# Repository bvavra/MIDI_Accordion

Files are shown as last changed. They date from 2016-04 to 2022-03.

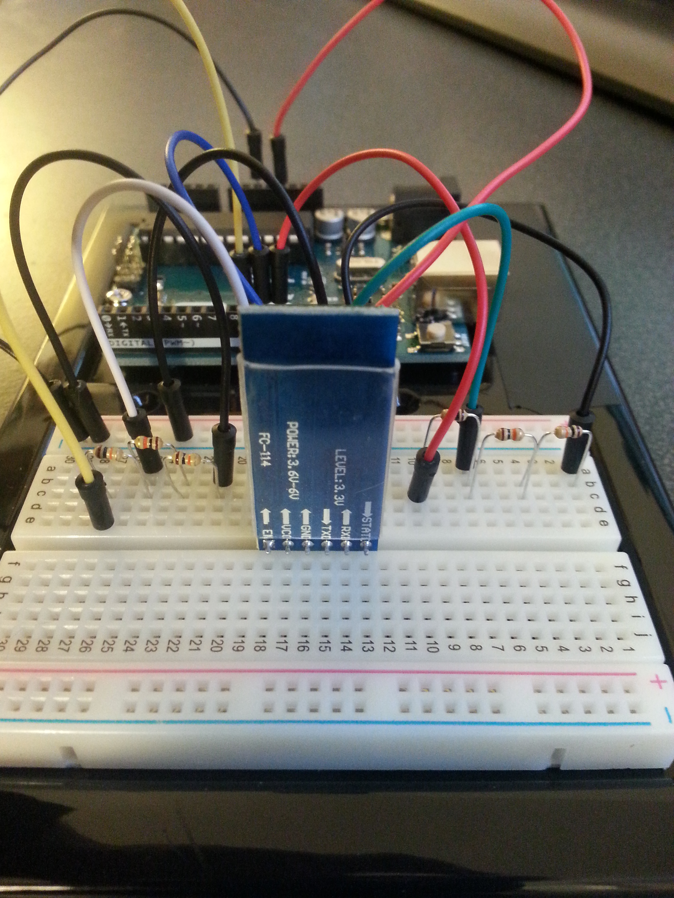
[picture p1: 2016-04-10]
Prototypes/Bluetooth/Bluetooth_Tutorial_2/bluetooth_fig2b_arduino.jpg

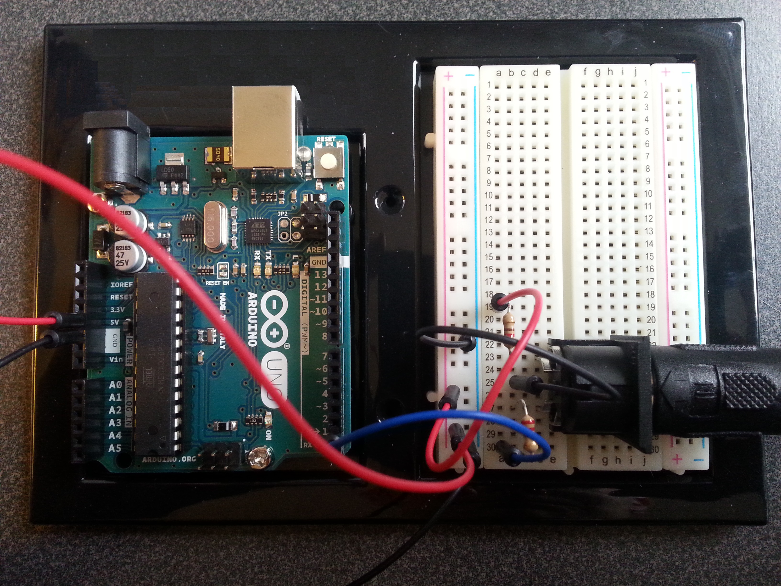
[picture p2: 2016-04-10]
Prototypes/MIDI_Tutorial/midi_fig1_arduino.jpg

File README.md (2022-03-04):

# DIY MIDI Accordion
Schematics, code, and guide for building your own Arduino-powered MIDI accordion _(based off Dmitry Yegorenkov's [AccordionMega project](https://github.com/accordion-mega/AccordionMega))_

### [Full Project Page](http://bvavra.github.io/MIDI_Accordion/)

### [Donate](https://www.paypal.com/donate/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)

### Photos

[MIDI Accordion Project Photo Gallery](http://imgur.com/a/U7L83)

### Videos

[Demo Video #1 - Professor Layton Main Theme (Intro)](https://www.youtube.com/watch?v=s197ojk8npI)

[Demo Video #2 - Stolen Moments (by Oliver Nelson)](https://www.youtube.com/watch?v=Z_4_YdG65XQ)

[Demo Video #3 - Everfrost Peak (from Diddy Kong Racing)](https://www.youtube.com/watch?v=8d2E2YQPqnI)

[Demo Video #4 - Stickerbrush Symphony (from Donkey Kong Country 2)](https://youtu.be/sQWZQSPkWCQ)

| Table of Contents      |
| ---------------------- |
| [Overview](#overview)  |
| [Changelog](#changelog)|
| [Materials](#materials)|
| [Software](#software)  |
| [Quick Guide](#guide)  |
| [Links](#links)        |

## Overview

The goal of this project is to take a traditional piano accordion and turn it into a MIDI controller capable of playing music through your computer.  To do this requires solving a few different problems; the finished MIDI Accordion needs to be able to:

1. Send a digital signal from the accordion keys and buttons to the computer
2. Convert that signal to MIDI
3. Play that signal back with music software
4. Communicate that signal for each button on the accordion

The above goals are enough to have a functional MIDI instrument, but there are a few additional "nice to have" requirements that can also be implemented, such as the ability to:

5. Communicate MIDI signals wirelessly (via Bluetooth)
6. Decouple the accordion's power supply from the computer/wall
7. Add dynamic expression using the accordion bellows (via barometric pressure sensor)
8. Add other expressions such as pitch bend, panning, and other sound control effects with potentiometers (sliders, knobs, joysticks, etc.)

_Note: In the project, the computer is **required** for playback; this project does **not** involve installing speakers to play back MIDI-realized sound directly from the accordion.  I may delve into such a feat someday, but today is not that day._

## Changelog

### v1.3.00 (10/2/2017)

- Added joystick to control pitch bend
    - Can be configured (at compile time) to bend pitch up or down
	- Can be configured (at compile time) to bend pitch for melody, bass, and/or chords
- **Breaking Change!** - Opto-interruptor pin connections have been moved in order to free up analog and PWM pins for future components.  If you are upgrading to v1.3 from an earlier version you will need to adjust your Arduino pin connections and/or code.  [Schematics and Breadboard docs](https://github.com/bvavra/MIDI_Accordion/tree/master/MIDI_Accordion/schematics) have been updated accordingly.

### v1.2.00 (1/2/2017)

- Added BMP180 support, allowing changes in pressure from moving bellows to change MIDI expression (i.e. volume)
   - Made the following changes from the original [AccordionMega](https://github.com/accordion-mega/AccordionMega) BMP085 code:
       - Updated the temperature and pressure reading code to use SparkFun's BMP180 library.
	   - Updated pressure<->velocity mapping algorithm according to various play tests.
       - Pressure is now read asynchronously from the Arduino - adds approximately 2ms delay when enabled (original added delay was about 3-5ms).

### v1.1.00 (12/28/2016)

- Added Bluetooth support (e.g. HC-05), allowing MIDI data to communicate wirelessly instead of over USB
    - Uses #DEFINE variable to toggle between using USB and additional serial port at compile time to reduce bandwidth usage

### v1.0.00 (12/09/2016)

- First working version of final project with all accordion keys mapped according to bvavra's PCB design.
- Made the following changes from the original [AccordionMega](https://github.com/accordion-mega/AccordionMega) code:
    - Updated files (and syntax) from .pde to .ino (new Arduino IDE)
    - Removed register shift code 
	    - Although it's a cool idea that could be realized on the accordion by adding some digital register buttons, I've decided to keep things simple and only transmit one register per button and control which registers sound via MIDI playback software (e.g. Logic, Reason, etc.)
    - Shaved off 2-3 ms of latency by reorganizing how the opto-interruptors are read.
    - Updated MIDI code to use Arduino MIDI Library
    - Added some extra comments to explain what some of the more obtuse lines are doing (port manipulation, bit operations, etc.)

## Materials

The final project requires the following materials and components:

**Item Name (Part Number)**|**Quantity**
:-----:|:-----:
Accordion|1
Arduino Mega 2560 R3|1
Barometric Pressure Sensor (BMP 180)|1
Bluetooth Transceiver Module (HC-05 RS232)|1
USB Bluetooth Dongle|1
Photo/Opto Interruptor (ITR-9608)|65
270 Ohm Resistor 1/4W 5%|65
1k Ohm Resistor 1/4W 5%|9
2k Ohm Resistor 1/4W 5%|1
BJT NPN Transistor (2N 2222A)|8
Black 8" Zip Ties|65
USB 2.0 Type A Type B M/M Cable|1
USB 2.0 Type A to Type B F/F Adapter Header|1
SB404 PCB (BB400)|2
BR1 PCB (830)|5
.5"x.5" 90 Degree Angle Corner Plate (H# 884487)|10
2.54mm Breakaway PCB Board 40 Pin Header Kit|1
2.54mm Dupont M/F 40 Pin Connector Kit|1
Multicolored Jumper Wire Ribbon Cable Kit|1
M3 M/F Brass Spacer Standoff Assortment Kit|1
Threaded Insert M3 9.52mm|8
White 4" Zip Ties (100pc)|1

The total cost of these materials can vary. [The original accordion project](https://github.com/accordion-mega/AccordionMega/wiki/Accordion-Mega-story) cost under $100.  If you exclude the accordion, I spent about $220 on the above materials.  If you don't have an accordion you can get a decent enough one on eBay for as low as $100 (normally I'd advise against buying an accordion off eBay, but it doesn't have to sound good; it just needs to function mechanically).  I bought mine for $150 (plus $30 shipping), bringing my project's grand total cost to about $400.

You will also need the following tools:

**Item**|**Usage**
:-----:|:-----:
Multimeter|Used to debug circuit connectivity.
Soldering Iron|Used to join components to the circuit boards.
60-40 Rosin Core Solder|Used to create circuit joints.
Brass Wire and Holder|Used to clean the soldering iron tip.
Desoldering Wick/Pump/Bulb|Used to fix soldering mistakes.
Adjustable Circuit Board Holder|Used to hold the circuit board in place while soldering.
Wire Strippers|Used to cut and strip wires to size.
Wire Cutters|Used to trim wires and components after they've been soldered.
Utility Knife|Used to cut the circuit boards and sever bad solder connections.
Sandpaper|Used to smooth cuts made to circuit boards.
Power Drill|Used to drill holes in the circuit boards and the accordion.
Small Flathead Screwdriver (c.1/8")|Used to open up and take apart the accordion.
Crimping pliers|(Optional) Used to make jumper wire ends.

I had to buy most of these tools for this project, which rang up to about $100 total.

## Software

### Project Source Code

The only files required for the final project are the Arduino files located in the root level [MIDI_Accordion directory](https://github.com/bvavra/MIDI_Accordion/tree/master/MIDI_Accordion).  Everything else in this repo is supplemental information to help research and build the project (e.g. Prototypes, Datasheets, Design docs, etc.).  Of course, you will need the [Arduino IDE](https://www.arduino.cc/en/main/software) to write and upload the project source code to your Arduino.

### Arduino Libraries

The following libraries are required to compile the MIDI_Accordion Arduino sketch:

- [Arduino MIDI Library](http://playground.arduino.cc/Main/MIDILibrary)
    - Used to simplify sending data via the MIDI protocol.
- [Sparkfun's Arduino BMP180 Library](https://github.com/sparkfun/BMP180_Breakout)
    - Used to interface with the BMP180 barometric pressure sensor.

### Third Party

To play your finished MIDI Accordion you'll need the following additional software:

- Serial-to-MIDI converter
    - Used to convert data coming from the Arduino from Serial to MIDI.  I recommend [Hairless MIDI <-> Serial Bridge](http://projectgus.github.io/hairless-midiserial/).
- Virtual MIDI port
    - Used to connect the MIDI data to playback software.  
	- [OSX configuration instructions](http://feelyoursound.com/setup-midi-os-x/)
	- [Linux (Debian/Ubuntu) config instructions](https://ubuntuforums.org/showthread.php?t=1445186)
	- Windows requires 3rd party software - I recommend [LoopMIDI](http://www.tobias-erichsen.de/software/loopmidi.html).
- MIDI controller/sequencer/player
    - Used to play back MIDI data triggered by the accordion.  It can be whatever your preferred MIDI playback software is (e.g. Logic, Reason, etc.), but if you don't have one I recommend using [Virtual MIDI Piano Keyboard (VMPK)](http://vmpk.sourceforge.net/), which is free and Windows/OSX/Linux compatible.
- (Optional) [ASIO4All](http://www.asio4all.com/)
    - Used to reduce latency when playing back MIDI on Windows machines without ASIO audio drivers.

## Project Quick Guide

This is meant to be a bare-bones guide to building your own MIDI accordion, providing only a general roadmap for those who already know what they're doing or for those who are curious about the process, but only want a tl;dr.  You can view the [complete guide here](http://bvavra.github.io/MIDI_Accordion/).  I also provided a [set of links](#links) that were helpful to me in getting my project up and running - if any of them are broken please let me know and I'll update the list accordingly.

Note: Although this guide is labelled as "quick", the project itself is not.  Between researching, building prototypes, making a lot mistakes (and learning from them), and designing/building/testing the final product, I spent over 200 hours on this project.  However, I made this guide in hopes that others can do this project with all the necessary information and resources available in one place, which I believe will enable future makers to complete this project in far less time.

### Basic Assembly/Installation Instructions

_In-depth instructions can be found on the [**MIDI Accordion Project Page**](http://bvavra.github.io/MIDI_Accordion/)_

#### [Sending MIDI data from the Arduino](http://bvavra.github.io/MIDI_Accordion/sending-midi/) and [playing it back with music software](http://bvavra.github.io/MIDI_Accordion/midi-playback/)

1. Upload the [MIDI_Tutorial](https://github.com/bvavra/MIDI_Accordion/tree/master/Prototypes/MIDI_Tutorial) prototype to your Arduino.
2. Install the Serial-to-MIDI conversion software of your choice (e.g. [Hairless MIDI](http://projectgus.github.io/hairless-midiserial/))
3. Install (or configure) a virtual MIDI port (e.g. [LoopMIDI](http://www.tobias-erichsen.de/software/loopmidi.html)) and configure the Serial-to-MIDI converter to send data from the connected Arduino to the virtual MIDI port.
4. Open the MIDI playback software of your choice (e.g. [VMPK](http://vmpk.sourceforge.net/)) and configure the MIDI input to read from the virtual MIDI port.  At this point you should hear MIDI being played by the Arduino.

#### [Mapping Accordion button and key presses to digital MIDI signals](http://bvavra.github.io/MIDI_Accordion/opto-interruptor/)

1. Build and upload the [Opto_Interruptor_1](https://github.com/bvavra/MIDI_Accordion/tree/master/Prototypes/Opto_Interruptor/Opto_Interruptor_1) prototype to your Arduino and assert the following:
	1. When the interruptor is blocked, the digital output is HIGH.
	2. When the interruptor is unblocked and the input pin is HIGH, the digital output is LOW. 
	3. When the interruptor is unblocked and the input pin is LOW, the digital output is HIGH.
2. [Cut and mount opto-interruptor blockers](http://bvavra.github.io/MIDI_Accordion/accordion/) to each of the 24 key pads on the left hand and each of the 41 keys on the right hand.  I did this by [cutting and gluing zip ties to the bottom of the keypads](http://i.imgur.com/JqKlctF.jpg) and [mounting circuits inside the bellows](http://i.imgur.com/5CT6w8J.jpg), whereas Dmitry [attached metal rods on the other side of the keypads](http://dimon.shopopalo.com/arduino/left_hand_24.jpg).  You can choose whichever method works best for you and your accordion.
3. Test that the blockers work by uploading the [MIDI_Accordion](https://github.com/bvavra/MIDI_Accordion/tree/master/MIDI_Accordion) sketch to your Arduino, wiring a prototype of 1 or more opto-interruptors away from the breadboard (using M/F jumper wires), and [temporarily adhering them over the blockers](http://i.imgur.com/zXNV6vj.jpg?1) where they will be for the finished product.  Pressing the corresponding accordion keys when all the MIDI software is running should trigger sound playback (though the pitches may be incorrect).
	
#### [Designing](http://bvavra.github.io/MIDI_Accordion/circuit/), [building](http://bvavra.github.io/MIDI_Accordion/assembly/), mounting, and wiring the circuits

1. Design and build circuits for each of the keys that need to be mapped according to the [final project schematics](https://raw.githubusercontent.com/bvavra/MIDI_Accordion/master/MIDI_Accordion/schematics/MIDI_Accordion_schem.png).  You can refer to [these design docs](https://github.com/bvavra/MIDI_Accordion/tree/master/pdf/design), [this Fritzing reference](https://raw.githubusercontent.com/bvavra/MIDI_Accordion/master/MIDI_Accordion/schematics/MIDI_Accordion_bb.png), and my [project photos](http://imgur.com/a/U7L83) for reference.
	* Note: Each accordion is different, so the designs that worked for my accordion may not work for yours.  Stick to the schamtics and plan your boards accordingly.  Be sure to leave enough room for wires to connect everything and for the accordion to be closed up.
2. Mount the circuit boards to the accordion and wire everything together.  If you plan on adding the BMP180 for bellow expression, be sure to provide enough slack for the wires connecting the treble and bass side to allow for pulling the bellows out.
3. Drill a hole to allow for connecting the USB cable from the Arduino to the computer and [mount the USB port in the hole](http://i.imgur.com/rvxLVdk.jpg?1).
4. Once [everything is connected](http://i.imgur.com/3HWcnyW.jpg), upload the [MIDI_Accordion](https://github.com/bvavra/MIDI_Accordion/tree/master/MIDI_Accordion) sketch to your Arduino, open all of your connection software, and [test that every key works properly](http://bvavra.github.io/MIDI_Accordion/testing/) by asserting that the key doesn't stick and that the key or button plays the correct pitch(es).  You will likely have to adjust the pitch mappings in the code based on how you organized and wired your sensor circuits.
	
#### (Optional) Communicating MIDI signals wirelessly via Bluetooth

1. Upload the [Bluetooth_Tutorial](https://github.com/bvavra/MIDI_Accordion/tree/master/Prototypes/Bluetooth/Bluetooth_Tutorial) prototype to your Arduino and follow the instructions on [this instructables page](http://www.instructables.com/id/Cheap-2-Way-Bluetooth-Connection-Between-Arduino-a/?ALLSTEPS) to hook up the transceiver to the Arduino, configure it with your Bluetooth receiver, and test that it works properly.
2. Upload the [Bluetooth_Tutorial_2](https://github.com/bvavra/MIDI_Accordion/tree/master/Prototypes/Bluetooth/Bluetooth_Tutorial_2) prototype to your Arduino and follow the instructions on [this instructables page](http://www.instructables.com/id/Modify-The-HC-05-Bluetooth-Module-Defaults-Using-A/?ALLSTEPS) to access the Bluetooth transceiver's AT mode.  While in AT mode, update the baud rate to 115,200 kb/sec by entering the command "AT+UART=115200,1,0".  You can optionally also change the name and password of the Bluetooth device.
3. If you haven't already, [solder, mount, and wire a circuit board for the HC-05](http://i.imgur.com/t24RJP1.jpg) according to the given [design](https://raw.githubusercontent.com/bvavra/MIDI_Accordion/master/MIDI_Accordion/schematics/MIDI_Accordion_bb.png) and [schematics](https://raw.githubusercontent.com/bvavra/MIDI_Accordion/master/MIDI_Accordion/schematics/MIDI_Accordion_schem.png).
4. Open the [MIDI_Accordion](https://github.com/bvavra/MIDI_Accordion/tree/master/MIDI_Accordion) sketch and uncomment the "//#define BLUETOOTH" line of code to enable the bluetooth serial port.  Upload the changes to your Arduino. 
5. Update your Serial<->MIDI conversion software to point to the Bluetooth COM port instead of the Arduino port.
6. (Optional) Instead of plugging the Arduino into the computer via USB cable, you can now use a battery pack to power the accordion.  A 4xAA pack is recommended, but certain 5V USB phone charger packs may also work (but I haven't tested this yet, so your mileage may vary).
	
#### (Optional) Adding dynamic expression using the accordion bellows via barometric pressure sensor

1. If you haven't already, [solder, mount, and wire a circuit board for the BMP180](http://i.imgur.com/t24RJP1.jpg) according to the given [design](https://raw.githubusercontent.com/bvavra/MIDI_Accordion/master/MIDI_Accordion/schematics/MIDI_Accordion_bb.png) and [schematics](https://raw.githubusercontent.com/bvavra/MIDI_Accordion/master/MIDI_Accordion/schematics/MIDI_Accordion_schem.png).
2. Open the [MIDI_Accordion](https://github.com/bvavra/MIDI_Accordion/tree/master/MIDI_Accordion) sketch and uncomment the "//#define BMP" line of code to enable using the BMP180 to map bellow pressure to MIDI expression.  Upload the changes to your Arduino. 
3. Cover as many unused air holes in the accordion bellows as possible to maximize the amount of air resistance you will feel when squeezing the bellows.
4. (Optional) The bellows may not feel right based on your playing style or the amount of air resistance.  To improve this, you may need to tweak the numbers in the function used to map the difference in air pressure to MIDI expression values.

#### (Optional) Adding a joystick to pend pitch when pressing the master palm switch

1. Solder, mount, and wire a circuit board for a mini joystick so it [gets triggered when you press the register switch](https://i.imgur.com/hfIESQA.gif).
2. Open the [MIDI_Accordion](https://github.com/bvavra/MIDI_Accordion/tree/master/MIDI_Accordion) sketch and uncomment the "//#define JOYSTICK" line of code to enable mapping the joystick tilt to MIDI pitch bend data. 
3. Adjust the configuration variables in [Pitch_Bend.ino](https://github.com/bvavra/MIDI_Accordion/blob/master/MIDI_Accordion/Pitch_Bend.ino) as desired.

## Links

The following links were helpful in making this project happen.  If any of these links are broken, or if you have any additional links that you found helpful, please [contact me](https://github.com/bvavra/MIDI_Accordion/issues) and let me know so I can update this list accordingly.

### Accordion

- [Lots of accordion repair resources](http://www.accordionrevival.com/Home.php)
- [Taking apart the Stradella bass system](http://paisanoaccordions.blogspot.com/2009/09/not-for-faint-of-heart.html)
- [Taking apart the piano keyboard](http://www.instructables.com/id/How-to-fix-an-accordion-keyboard/)
- [Accordion repair videos](http://www.ehow.com/videos-on_2531_apart-accordion.html)
- [Accoridon repair tools](http://accordionplus.com/tools.html)

### Arduino

- [Internal pullup resistor tutorial](https://www.arduino.cc/en/Tutorial/InputPullupSerial)
- [Info about switches](http://www.gammon.com.au/switches)
- [Arduino baud rates](http://arduino.stackexchange.com/questions/296/how-high-of-a-baud-rate-can-i-go-without-errors)
- [Arduino port manipulation](https://www.arduino.cc/en/Reference/PortManipulation)
- [Port manipulation tutorial](http://www.instructables.com/id/Arduino-is-Slow-and-how-to-fix-it/?ALLSTEPS)
- [Another port manipulation tutorial](http://www.instructables.com/id/Fast-digitalRead-digitalWrite-for-Arduino/?ALLSTEPS)
- [Organizing Arduino code with tabs](https://liudr.wordpress.com/2011/02/16/using-tabs-in-arduino-ide/)

### MIDI

- [MIDI Protocol essentials](https://ccrma.stanford.edu/~craig/articles/linuxmidi/misc/essenmidi.html)
- [Arduino MIDI Library docs](http://fortyseveneffects.github.io/arduino_midi_library/index.html)
- [MIDI CC List](http://nickfever.com/music/midi-cc-list)
- [Send and receive MIDI with Arduino](http://www.instructables.com/id/Send-and-Receive-MIDI-with-Arduino/?ALLSTEPS)
- [When does audio latency matter and not matter?](http://music.stackexchange.com/questions/30323/when-does-audio-latency-matter-and-not-matter)
- [Latency problem using MS GS Wavetable Synth](https://answers.microsoft.com/en-us/windows/forum/windows_7-pictures/latency-problem-using-ms-gs-wavetable-synth/1e85704a-803c-438f-b472-fb0cb5211be4)
- [Reducing latency on MIDI-over-USB keyboard](http://sound.stackexchange.com/questions/27583/reducing-latency-on-midi-over-usb-keyboard)
- [Arduino MIDI Expression Pedal](https://www.codeproject.com/articles/38203/arduino-based-midi-expression-pedal)
- [Difference between MIDI velocity and Expression](http://www.sweetwater.com/insync/what-difference-between-midi-volume-expression/)
- ["Unexpected data byte" error when sending CC data over Hairless MIDI](https://github.com/projectgus/hairless-midiserial/issues/16)

### Opto-Interruptors

- [How To Set Up A Photo Interrupter (or Slotted Optical) Switch On The Arduino](http://www.utopiamechanicus.com/article/arduino-photo-interruptor-slotted-optical-switch/)
- [Connecting a photo interrupter/optoisolator to an Arduino](http://www.martyncurrey.com/connecting-an-photo-interrupter-to-an-arduino/)
- [ITR-9608 Datasheet](http://www.electrodragon.com/w/images/6/60/ITR9608.pdf)

### Bluetooth

- [Cheap 2-Way Bluetooth Connection Between Arduino and PC](http://www.instructables.com/id/Cheap-2-Way-Bluetooth-Connection-Between-Arduino-a/?ALLSTEPS)
- [Modify The HC-05 Bluetooth Module Defaults Using AT Commands](http://www.instructables.com/id/Modify-The-HC-05-Bluetooth-Module-Defaults-Using-A/?ALLSTEPS)
- [Arduino with HC-05 Bluetooth module - AT MODE](http://www.martyncurrey.com/arduino-with-hc-05-bluetooth-module-at-mode/)

### Barometric Pressure Sensor

- [BMP180 Barometric Pressure Sensor Hookup](https://learn.sparkfun.com/tutorials/bmp180-barometric-pressure-sensor-hookup-)

### Power

- [Feeding power to Arduino: the ultimate guide](http://www.open-electronics.org/the-power-of-arduino-this-unknown/)
- [Arduino power sharing](http://electronics.stackexchange.com/questions/36947/arduino-power-sharing)
- [9V is not a good power source](http://cybergibbons.com/uncategorized/arduino-misconceptions-6-a-9v-battery-is-a-good-power-source/)
- [Arduino power switch](http://www.instructables.com/id/Powering-Arduino-with-a-Battery/)
- [Is it bad practice to provide power through the VIN Pin?](https://www.reddit.com/r/arduino/comments/2jdyba/is_it_bad_practice_to_provide_power_through_the/)
- [Powering an Arduino Mega with external USB Power Bank?](http://arduino.stackexchange.com/questions/9069/powering-an-arduino-mega-with-external-usb-power-bank)

### Wiring

- [Soldering 101 (adafruit)](https://learn.adafruit.com/lets-put-leds-in-things/soldering)
- [How to solder electronics (wikiHow)](http://www.wikihow.com/Solder-Electronics)
- [How to solder (instructables)](http://www.instructables.com/id/How-to-solder/?ALLSTEPS)
- [Basic de-soldering guide](http://www.epemag.wimborne.co.uk/desolderpix.htm)
- [Custom Cables & Guide to Crimping Dupont PCB Interconnect Cables](https://www.youtube.com/watch?v=GkbOJSvhCgU)

### Electronics

- [How to read a schematic](https://learn.sparkfun.com/tutorials/how-to-read-a-schematic)
- [Understanding the functions of a multimeter](https://learn.adafruit.com/multimeters/)
- [Light-Emitting Diodes (LEDs)](https://learn.sparkfun.com/tutorials/light-emitting-diodes-leds)
- [How to test diodes using a digital multimeter](http://en-us.fluke.com/training/training-library/test-tools/digital-multimeters/how-to-test-diodes-using-a-digital-multimeter.html)
- [Why exactly can't a single resistor be used for many parallel LEDs?](http://electronics.stackexchange.com/questions/22291/why-exactly-cant-a-single-resistor-be-used-for-many-parallel-leds)
- [8 Tips On How To Pick A Resistor For An Arduino (Circuit)](http://www.utopiamechanicus.com/article/arduino-resistor-selection/)
- [Voltage Dividers tutorial](https://learn.sparkfun.com/tutorials/voltage-dividers)
- [Transistors tutorial](https://learn.sparkfun.com/tutorials/transistors)
- [How transistors work](http://www.build-electronic-circuits.com/how-transistors-work/)

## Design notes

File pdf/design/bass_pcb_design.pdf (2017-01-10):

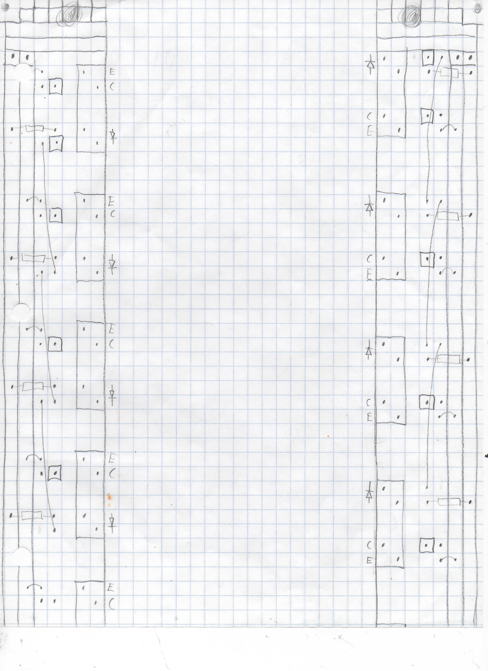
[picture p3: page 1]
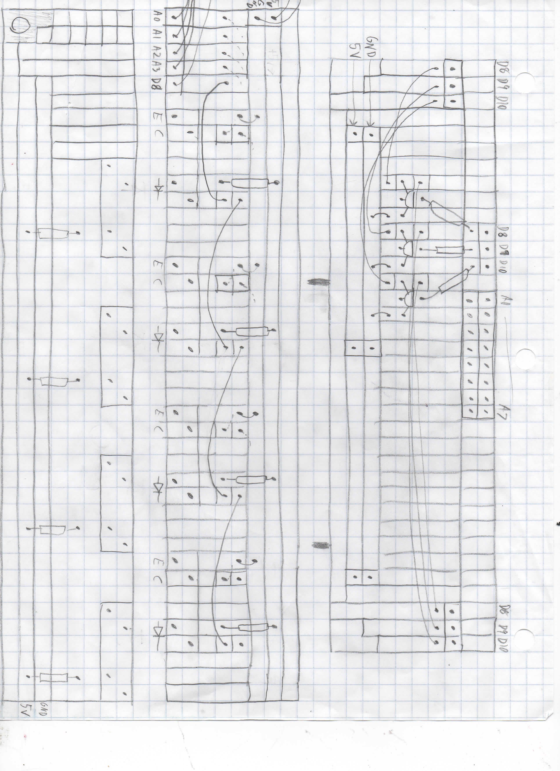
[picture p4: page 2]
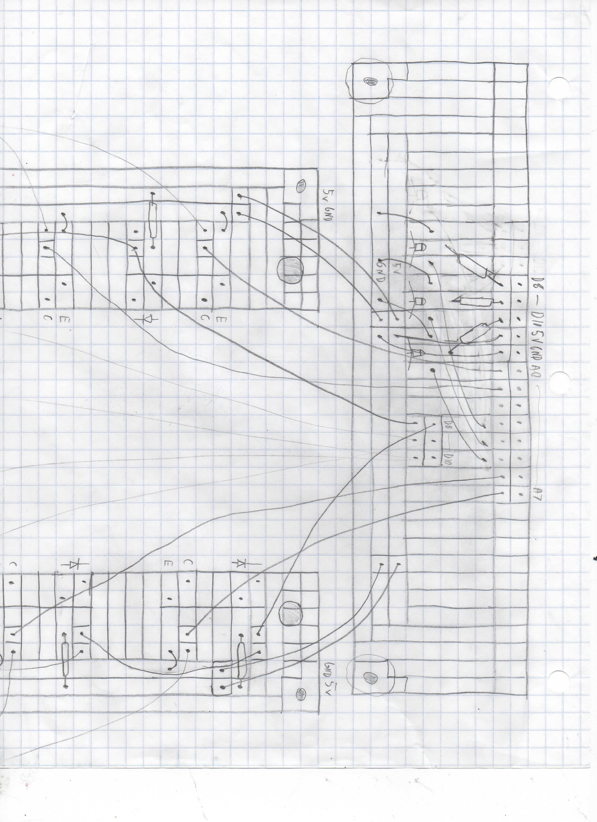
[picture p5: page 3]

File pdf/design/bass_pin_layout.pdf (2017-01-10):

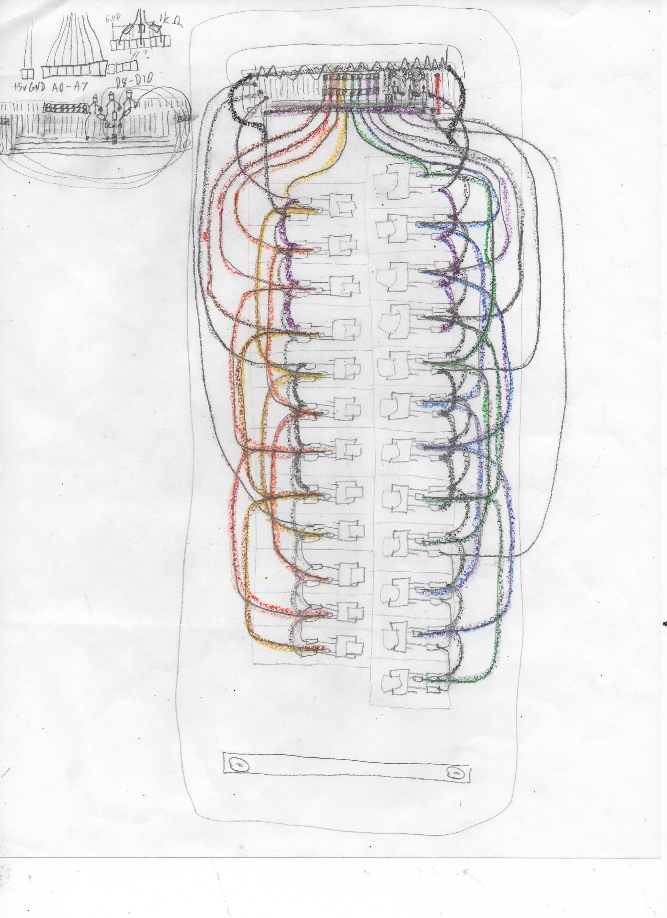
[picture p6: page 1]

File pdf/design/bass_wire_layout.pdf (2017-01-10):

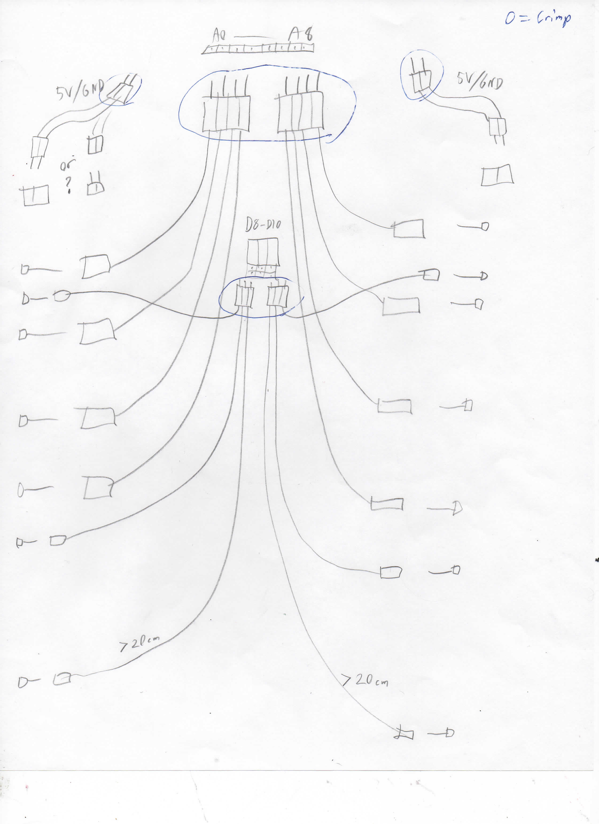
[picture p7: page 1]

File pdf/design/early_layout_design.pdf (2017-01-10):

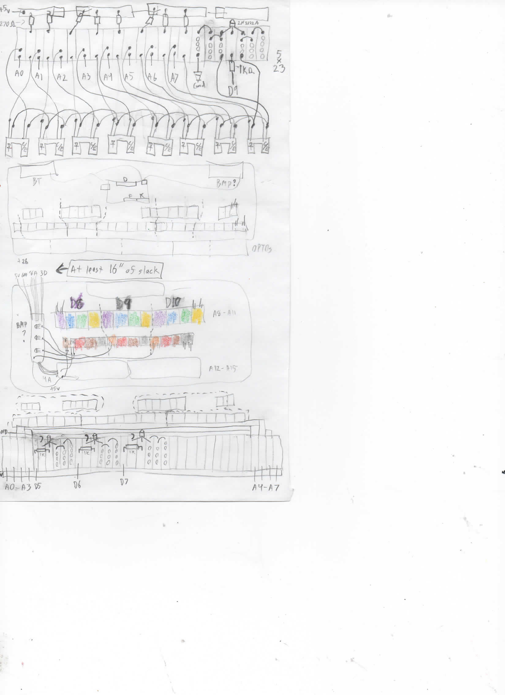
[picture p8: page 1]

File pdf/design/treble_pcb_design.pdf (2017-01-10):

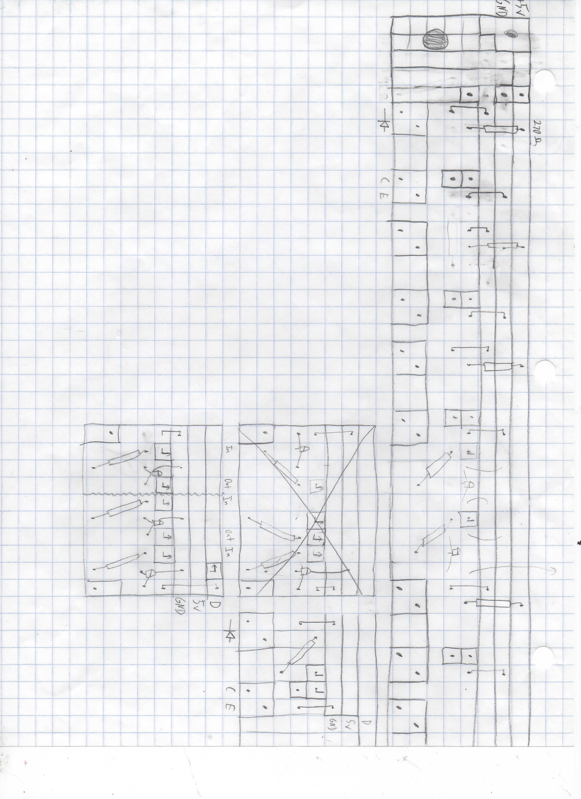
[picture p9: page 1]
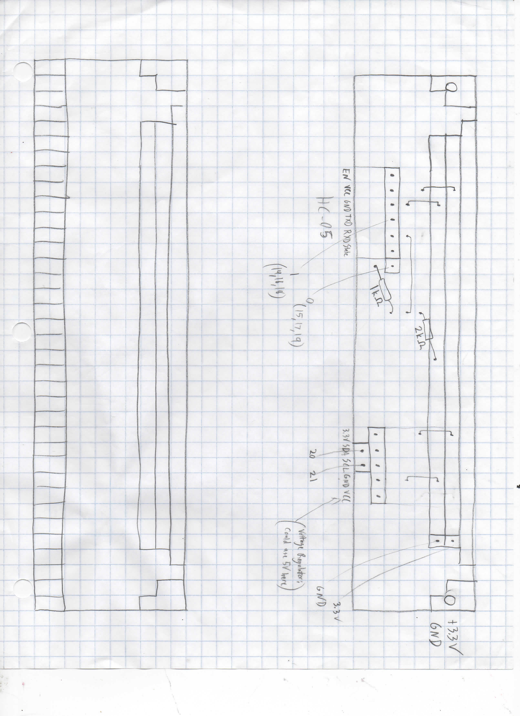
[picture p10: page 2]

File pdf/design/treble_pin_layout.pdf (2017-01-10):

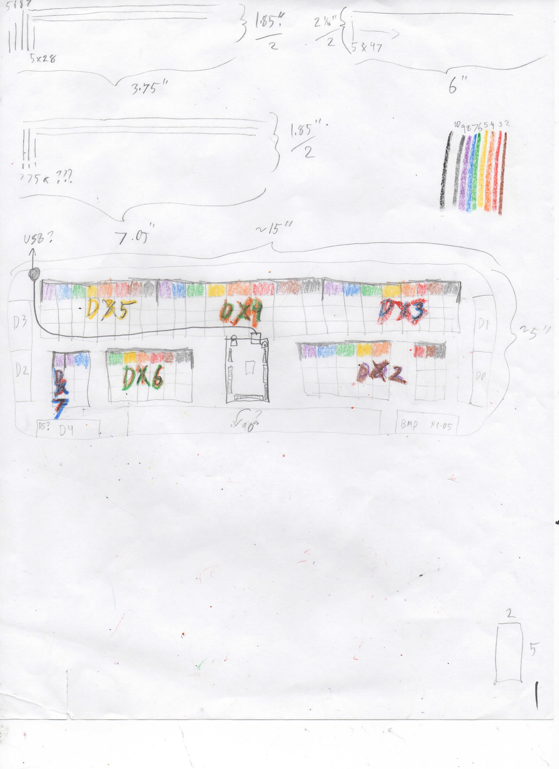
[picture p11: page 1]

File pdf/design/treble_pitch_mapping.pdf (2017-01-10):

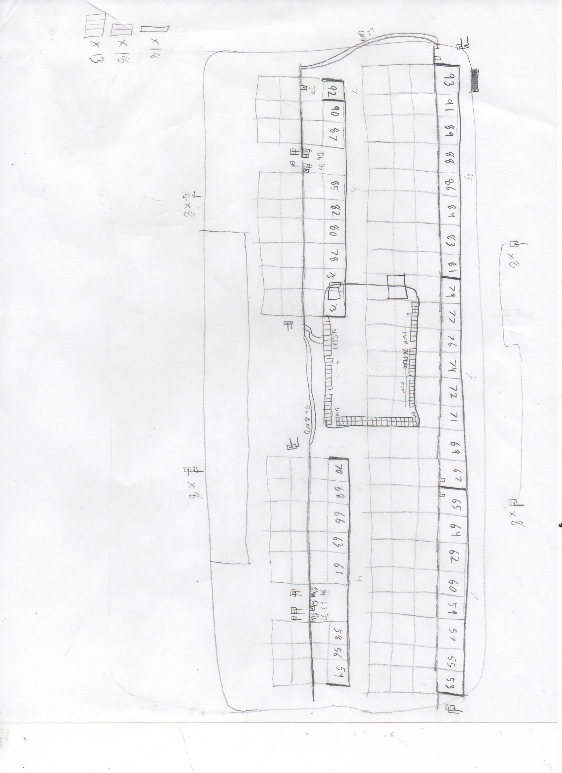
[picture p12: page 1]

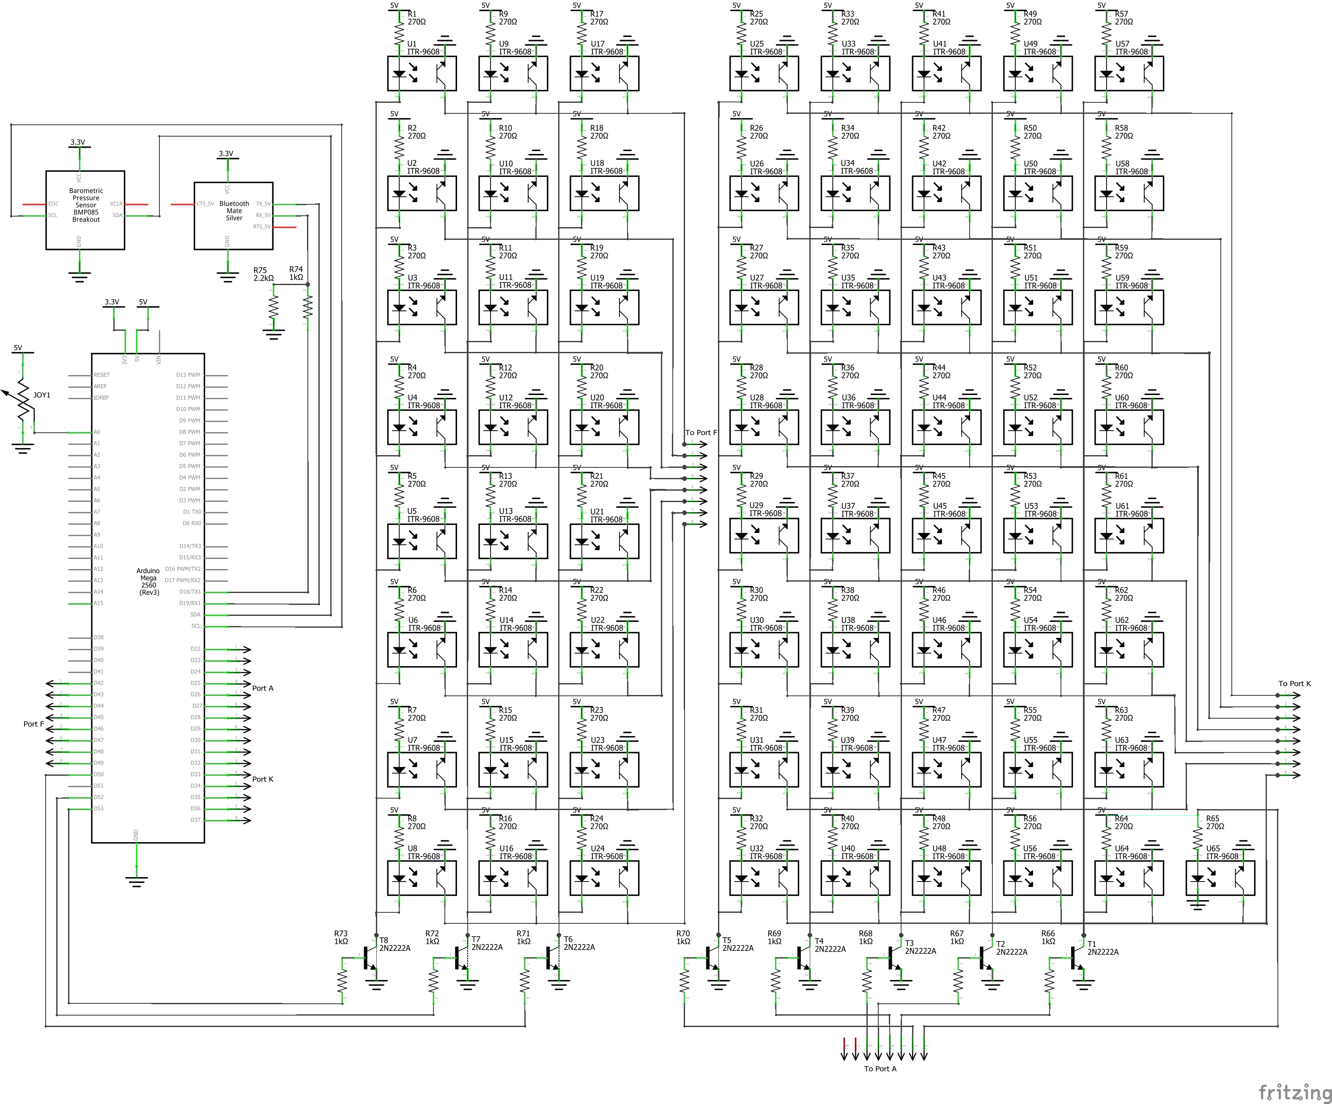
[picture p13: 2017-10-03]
MIDI_Accordion/schematics/MIDI_Accordion_schem.png

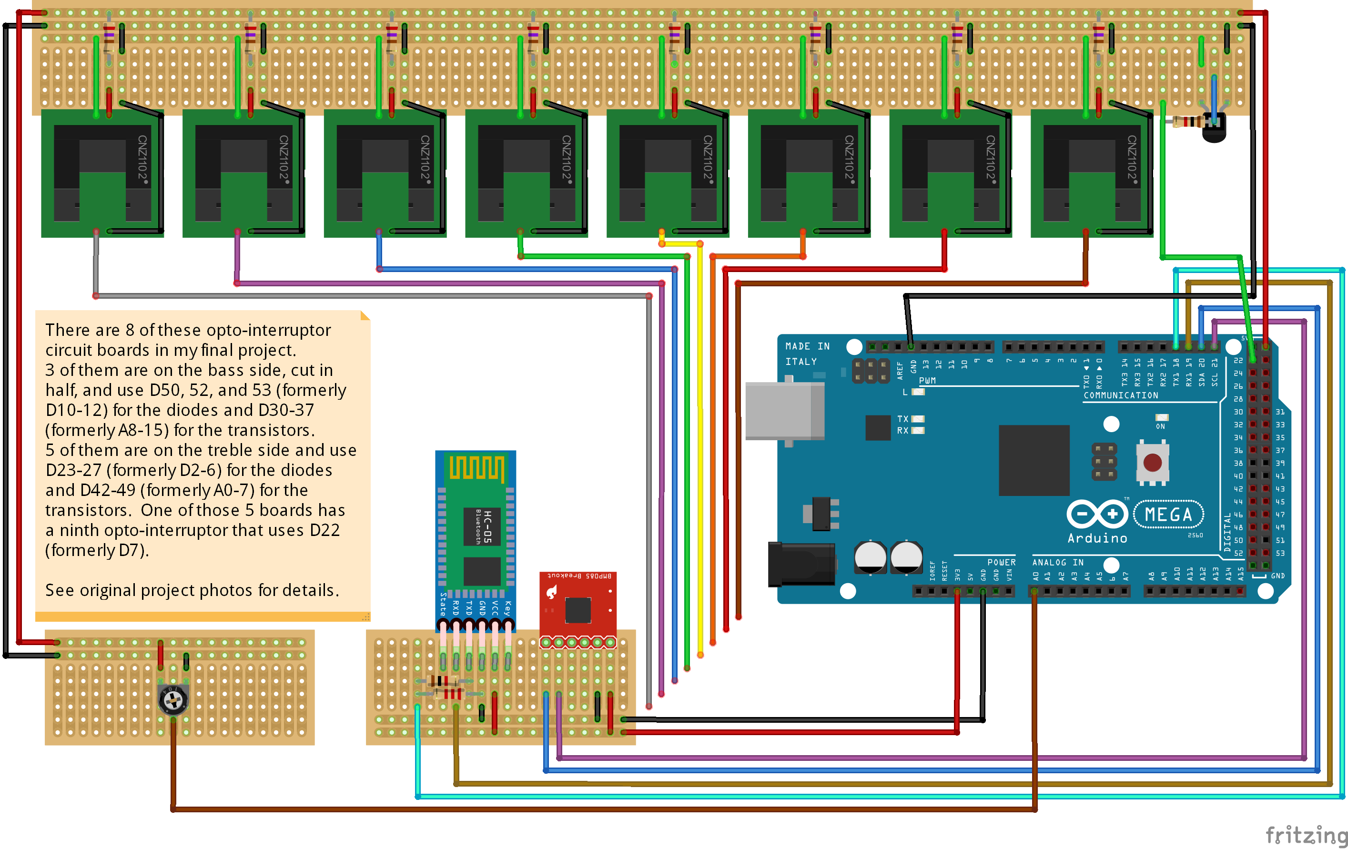
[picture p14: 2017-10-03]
MIDI_Accordion/schematics/MIDI_Accordion_bb.png

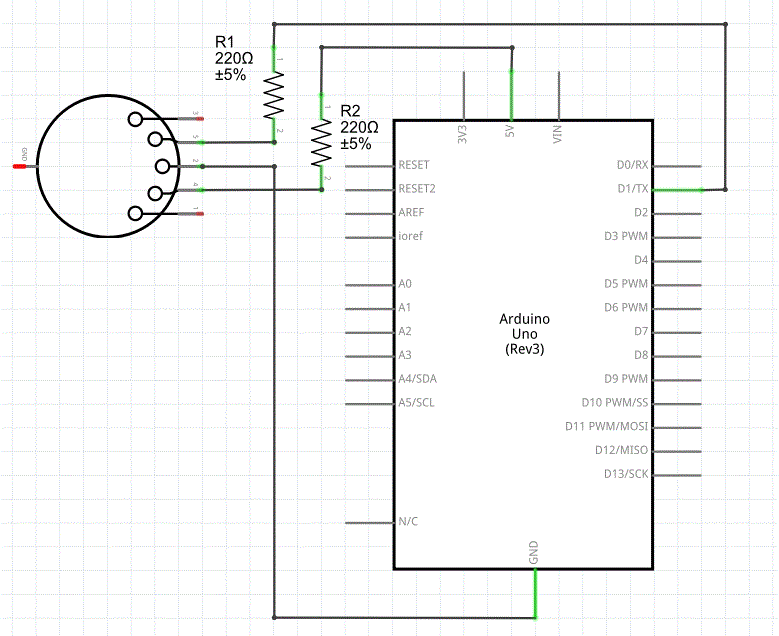
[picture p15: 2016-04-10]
Prototypes/MIDI_Tutorial/midi_schematic.GIF

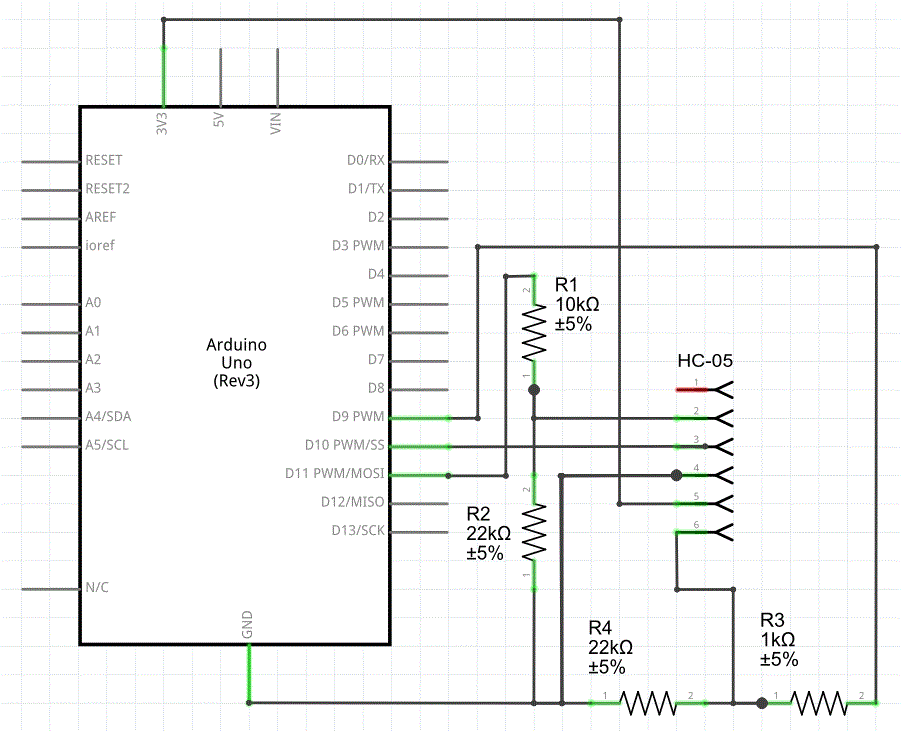
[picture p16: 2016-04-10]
Prototypes/Bluetooth/Bluetooth_Tutorial_2/bluetooth_schematic_2.GIF

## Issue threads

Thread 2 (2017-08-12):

Problem with schematics: interal pull-up resistor in Arduino is too weak

mojca, 2017-08-12:
First of all, let me express a deep gratitude for providing so accurate description of the project. I blindly ordered a bunch of opto interruptors (ITR-9608) for [our project](https://wiki.mittelab.org/progetti/mojca/accordion), but I could not get them working by following your schematic and it took me quite a bit of exploring until we realized where the problem was.

This schematic finally worked:
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

It turned out that Arduino's internal 50k (or whatever the exact value is) internal pull up is simply too weak. The problem was solved for me after adding additional 1k resistors next to Arduino's diginal inputs and configure the ports as regular input rather than `INPUT_PULLUP`. We then even managed to use Arduino nano for the accordion thanks to your idea rather than having to depend on Mega (even though we'll probably still use Mega at the end).

I accidentally bought two hundred 470 Ohm resistors instead of cca. 180-270 Ohm (it was the shop's fault) and ended up with cca. 1 V when the switch was OFF, but that still translated to nice zeroes at the digital input.

I wonder how that schematic could have worked for you unless your opto interruptors were slightly different.

bvavra, 2017-08-12:
Hiyo,

Wow, your project looks amazing, and I'm wildly impressed you were able to do so much in a single week (including building the box itself)!  And thank you for adding my project to your credits. :)

Re: your issue - I'm surprised that the Arduino's internal pullup resistors (which I believe are 20k Ω) didn't work for you, because I also used the ITR-9608 and didn't have a problem.  The only guess I have is based on your schematic above that says the signal is going to a digital pin - although my code is doing a digital read against the port, the interruptor is actually connected to an analog pin, not digital, so that difference may possibly be the source of your issue.  I had tried connecting the interruptor to a digital pin during development and it did not work properly, but I did not try experimenting with the pullup resistor value or anything else to fix it, and instead went forward with using the analog pins.

mojca, 2017-08-12:
No, the box itself was lasercut upfront because bringing the laser to the camp was not realistically doable.

I actually tested with analogue inputs and kept reading the analogue value. The difference was there, but it was around 20 units out of 1024 if I recall correctly. Note that I was using both ITRs and Arduino nano clones ($5) from eBay. Maybe exact characteristics are slightly different from originals. After switching to 1k resistors I started getting really nice jumps from 110 to 960 (0.5 to 5 V) and it worked on both analogue and digital ports. (After connecting everything we realised that nano doesn't support digitalRead on A6 and 7.)

I can repeat the experiment on Mega's analogue pin though.

bvavra, 2017-08-13:
Hmm - I can't imagine the difference should be so significant between the Mega and a Nano clone, but I can't say for sure.

I tested one of my ITRs against [my initial prototype](https://github.com/bvavra/MIDI_Accordion/tree/master/Prototypes/Opto_Interruptor/Opto_Interruptor_1) on an Arduino Uno and had no problem getting good reads with this setup:

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

```
//ITR blocked
D9 HIGH: Value for analog PIN: 1012
Value for analog PORT: 11000000

D9 LOW: Value for analog PIN: 1011
Value for analog PORT: 11000000

//ITR unblocked
D9 HIGH: Value for analog PIN: 35
Value for analog PORT: 11000100

D9 LOW: Value for analog PIN: 162 //a bit of a jump here, but not enough to flip the bit value
Value for analog PORT: 11000000
```

I also tested this with a digital pin instead of analog and the digital port reads did still work correctly, to my surprise, so perhaps that's not the issue you're having.

Sidenote: the transistor is not required for a single interruptor (you could write the pin HIGH and LOW from the LED anode instead), but I included it in this sketch because it is required to drive down the current when reading 8 of them at a time, and I wanted to get it set up correctly so I had less moving parts when changing how many rows and/or columns of interruptors I had hooked up.

mojca, 2017-08-14:
Please give me some time to do some further testing and measurements (and to repeat the theory of transistors to try to come up with potential explanation). It could also be that transistors used in non-original ITR9608 switches could be different just enough to cause this effect. (I had the same effect when I replaced my own/external 1k pull-up with a 100k pull-up resistor.)

A local electronics store would need 3-5 weeks to deliver these optointerruptors, eBay/aliexpress with DHL was much faster and I have no clue where they come from.

mojca, 2017-08-15:
I went through some more consistent testing and I suspect I know what went wrong.

In the initial testing with super limited time that I had available the code for reading registers with Nano didn't work out of the box on nano (or maybe the wiring was wrong or whatever else), so I wrote all the code myself. I must have used
```
pinMode(3, INPUT_PULLUP);
```
instead of
```
pinMode(A3, INPUT_PULLUP);
```
To read from A3.

That made the values jump between roughly 1014-1023 with pretty high noise, so distinguishing the values would be nearly impossible.

When I added the external pull-up resistor it started working because the pin was configured for normal input by default.

In today's repeated test using a 220 Ohm resistor for the diode and 100k resistor as pull-up on the transistor side leads to jumps from roughly 15 to 1010 which is perfect. It also works just fine with the internal pull-up once I configured it properly.

Once we had the "PCB" ready and the correct code in place, I didn't try to change the schematic and my colleague had enough time with other aspects of the project, so he never even checked what I did (well, he did spend one full day with wire-wrapping tool :).

Sorry for the wrong diagnosis. And many many many thanks for the wonderful project description which made our project & experience a lot less painful.

bvavra, 2017-08-16:
No problem - I'm happy you figured it out and got everything working.  Sometimes you just need a [rubber duck](https://en.wikipedia.org/wiki/Rubber_duck_debugging) to talk to. :)

I'm glad my documentation was helpful to you.  It was my goal to not only build a working MIDI accordion, but to also document my work well enough to make this project as accessible as possible to others, and you are proof of that success.  If there's anything you think I can do to better document or explain certain aspects of the project, please let me know.

Closed 2017-08-15.

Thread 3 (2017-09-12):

Asking permission to use the code

M1nCh3, 2017-09-12:
Hi, my name is Wira, there is two thing i would say.
1. you realy done your  homework and you do awesome..salute!
2. just wondering if i just wanna use the code just to add more button on arduino mega without any air presure, so bassicly i just wanna make midi controller with 120 button, 16 potensio fader and 4 rotary encoder, is that possible if i use the code for it? and

bvavra, 2017-09-19:
Hello Wira,

Thank you!  If you want to build a MIDI controller that's not an accordion, I'm not sure that my code will be the best fit as it is currently written.  You may certainly use it as you like (as it's under the GNU general public license), but the code is designed to scan two matrices of opto-interruptors, and for your project it may be a lot simpler to use digital buttons instead.  There are existing libraries and ICs out there that make digital button scanning easy, such as the [SX1509](https://www.sparkfun.com/products/13601), which supports scanning up to an 8x8 button pad.  You can add up to 4 of of these to a single Arduino to support up to 256 buttons - see [this guide](https://learn.sparkfun.com/tutorials/sx1509-io-expander-breakout-hookup-guide#example-button-matrices) for details.

Regarding the faders and encoders - the Arduino Mega has 16 analog pins, which is just enough to support 16 potentiometer faders, and if you offload the button matrix to an IC like the SX1509 you should still have plenty of digital pins to support 4 rotary encoders.  If you need more pins, you can use a [multiplexer](https://learn.sparkfun.com/tutorials/multiplexer-breakout-hookup-guide) to add more digital or analog pins.

Closed 2017-10-03.

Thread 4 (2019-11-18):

5 din midi

denia85, 2019-11-18:
Thank you for your project. And it is possible to implement somehow connection through 5 din midi

bvavra, 2019-11-19:
Hiyo,

Yes, it is possible to use a standard MIDI cable instead of USB.  I mentioned this briefly on my [MIDI Playback](http://bvavra.github.io/MIDI_Accordion/midi-playback/) section of my in-depth guide: you can follow the [Arduino MIDI tutorial](https://www.arduino.cc/en/Tutorial/Midi) to attach a MIDI port to your Arduino's serial pin to transmit MIDI data from the Arduino through the MIDI port.  I've not done this with my project, so I haven't personally tested it with my MIDI accordion code, but I did research it as a viable option, and the existing links I posted in my MIDI guide should serve as a good starting point.

Closed 2019-11-19.

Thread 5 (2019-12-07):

bmp180

denia85, 2019-12-07:
Good afternoon.You wrote that it is possible to implement disabling bmp180 in the future .Could you point me how to do this

bvavra, 2019-12-09:
Hiyo,

See https://github.com/bvavra/MIDI_Accordion/blob/master/MIDI_Accordion/MIDI_Accordion.ino line 43 - BMP is disabled by default; you must uncomment this line to enable it.  This requires recompiling the code.  If you wanted to add a switch to turn it on and off at runtime, some code changes will be required (such as replacing the #define with a real variable and hooking to up to be toggled on and off).

bvavra, 2019-12-11:
From our email conversation:

> Yes about a more in-depth guide on how to do this. Could you share your experience?

Okay, I understand now.  That's correct, I haven't created a full page on this yet in my [in-depth guide](http://bvavra.github.io/MIDI_Accordion/overview/) yet; I will leave this issue open to do this.

In the meantime, I have basic steps in the [readme's quick guide](https://github.com/bvavra/MIDI_Accordion#guide), and you can follow the [Sparkfun tutorial](https://learn.sparkfun.com/tutorials/bmp180-barometric-pressure-sensor-hookup-) to get started on how to program for the BMP.  You can also check out [the prototypes I made](https://github.com/bvavra/MIDI_Accordion/tree/master/Prototypes/BMP) to start integrating using the BMP180 for MIDI control.

bvavra, 2019-12-24:
Ok, I added a [detailed page on using the BMP180](http://bvavra.github.io/MIDI_Accordion/volume/) - please let me know if this makes sense or if you have any other questions.

Closed 2019-12-24.

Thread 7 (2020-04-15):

Accordion midi - change opto interruptor

TheMaurice, 2020-04-15:
Hi, my name is Maurizio. I write from Rome. I saw your project and I really like it. I congratulate you. I have a Paolo Soprani 120 that works very well. I want to leave it like this but also add your midi circuit. Can I replace the Opto Interruptor (ITR-9608) with Hall Effect Reed Magnetic Sensors without changing the code? Thank you very much. (translated with Google)

bvavra, 2020-04-15:
Hello,

Thank you!  Trying to add the MIDI capability while leaving the reeds in place is quite the challenge.
 I personally have not looked into using hall sensors, so I cannot say with 100% certainty that replacing the optos with them will work without code updates.  At the very least, I will say I am performing digital reads on the optos, so the hall sensors you use will need to be able to send digital output signals (or at least, the Arduino will need to interpret the signal via digital read).  Otherwise you will need to update the code to use the analog pins instead of digital pins.  Either way, so long as you have the matrix of sensors set up the same way, no other significant changes should need to be made - only pin mapping.

Good luck with your project!

TheMaurice, 2020-04-17:
thank you so much for replying. the sensors that I plan to use are these https://it.wikipedia.org/wiki/Reed_(dispositivo). they are simple normally open on-off hall effect switches. now here in Italy we have a lot of time to stay at home. I had seen your project for a long time and wanted to carry it out. maybe this is the right time. Greetings. Maurizio

Closed 2020-05-02.

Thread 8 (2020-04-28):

Great Project - But - Bluetooth/Hairless/Lag is over 100ms

bwinterstine, 2020-04-28:
I re-used your schematics and code to build a midi accordion out of an old Excelsior accordion.  I really appreciate all the work you put into this!

My setup is: Midi Accordion, Genuine Arduino Mega, Bluetooth HC-05, 38400 Baud Rate ---> 2015 Macbook Pro with Hairless Serial App to Mainstage (for sounds).  Inside Mainstage, I set it up like this:  midi channel 5 for left hand Bass Notes, midi channel 4 for left hand Chords and midi channel 3 for right hand piano keys.  This all works well.

Problem:  When I play a note on the the accordion, any note, it takes approximately 120ms for the sound to be played.  I have attached a screenshot from Audacity.  I had recorded the sound of me hitting a note on the accordion and and the note being played on my Mac.  I used Audacity to analyze the time delay.  Also, I use Mainstage with USB Midi Keyboards and do not have any problems with latency on this Macbook.

Does anyone else have this problem?

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
![Uploading Midi Latency Measurement.png…]()

bvavra, 2020-04-28:
Hmm.  My knowledge on the Mac side is a bit lacking, so I can't comment on if anything is slowing it down on that end.  I'm reading that Mac Core Audio is not known to experience added latency (unlike Windows, where I had to use ASIO4All to make my accordion playable), so I'm going to assume there's no issue there.  Some other possible things to look into:

1. Have you tried using a USB connection instead of Bluetooth to see if the latency still exists over USB?
2. You mention using a baud rate of 38400 - have you tried using 115200?
3. Are you using the pressure sensor code at all?  If so, can you try turning it off to see if that has any noticeable impact (in theory it should only add 2-4ms).

bwinterstine, 2020-04-28:
Wow, fast reply!  Thanks.

I can use either the USB connection or bluetooth.  The USB connection has a latency of 86ms which is slightly better; I did try it.  I have tried other baud rates but the latency stays about the same.

I am not using the pressure sensor code, yet.  I want to get the basic midi accordion working well first.  My next step is to add some knobs and buttons to send midi control information to Mainstage.  The last step will be the pressure sensor.

I have the code stripped down to a bare minimum and I'm sure it is not contributing the the latency (your code works great and is pretty darn fast).

I think the problem is in hairless midi software compiled on the latest 64 bit MacOS.  I have reported a problem there also.

bvavra, 2020-04-28:
Awesome - sounds like you're doing pretty much the same thing I was.

If you determine Hairless MIDI to be the culprit, you could try cutting it out completely by updating the Arduino to send data directly as MIDI using [mocoLUFA](https://github.com/kuwatay/mocolufa).  Not sure how well that will work over bluetooth, but it should work fine over USB - that way the accordion would be recognized by the OS as a MIDI device.  I haven't tried this personally, but others who have done this and similar projects went this route with great results.

bwinterstine, 2020-04-29:
I found out today that my midi keyboard (Berhinger U-Control) has latency times of around 63ms.  This is way too high and I must have a problem in my MAC.  The same keyboard connected directly to my Korg Kronos workstation (via midi) has almost no detectable/measurable latency; around 10ms.  I need to do some investigation into my MAC and what it is doing to add all this latency.

bwinterstine, 2020-04-30:
I have determined that a large amount of the latency is in the MacBook
Pro.  The interface does go into sniff mode after a few seconds but the
latency continues when in active mode.   When in sniff mode, the first midi
data can take over 200ms.

I am thinking about buying a used Roland sound module but they would not
support the wireless bluetooth midi interface.

What were you using to receive bluetooth midi from the HC-05?

Bruce

On Tue, Apr 28, 2020, 11:07 AM Brendan Vavra <notifications@github.com>
wrote:

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

bvavra, 2020-05-01:
> What were you using to receive bluetooth midi from the HC-05?

I had just bought a standard bluetooth USB dongle and configured it using the Windows device configuration:

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

See also [Step 4 in this tutorial](https://www.instructables.com/id/Cheap-2-Way-Bluetooth-Connection-Between-Arduino-a/) for greater details.

> I am thinking about buying a used Roland sound module but they would not
support the **wireless bluetooth midi** interface.

I know Windows does not support this natively (which is why I don't use mocoLUFA), but I think OSX does. Something that might be worth trying (if you're not using this already) is the [Yamaha MD-BT01](https://usa.yamaha.com/products/music_production/accessories/md-bt01/index.html), which adds wireless bluetooth midi capabilities for OSX/iOS devices.

I recommend reaching out to @JasonBugeja to see if he ran into any latency issues like this - he has [his own MIDI Accordion projects](https://github.com/JasonBugeja?tab=repositories) that connect to OSX/iOS over bluetooth using the Yamaha MD-BT01, so he may be able to better help you with Mac compatibility than I can.

bwinterstine, 2020-05-01:
OK.  I think I’m going to build a Master bluetooth midi thru device to take the accordion bluetooth midi and convert it to a standard midi Tx DIN connector.  Then I can simply plug this into any midi compatible device and play the accordion thru it.  I will test it with my Korg Kronos and if it works well I will pick up an older Roland sound module.  Then, I can tailor some knobs and buttons on the accordion to change patches, volume and effects.

From all my testing I have discovered that my testing method has an inherent 20-30ms latency from the time the key is touched to the time the switch/contact senses the key press.  This is true of most instruments and this has to be subtracted from my previous test results.  Even an acoustic piano has a 20-30ms latency that really is never discussed.

After approximately 30 separate tests and measurements, I arrived at the following conclusions and estimates:

1.  The measurement technique I used has an inherent 30ms latency the numbers below show the actual latency measurements after this was subtracted.
2.  All direct USB connections to the MacBook are playable and the additional latency (from accordion software and MacBook processing) is between 11 to 50ms.
3.  Additional latency above 50ms becomes very noticeable.  This is the value to strive for (to keep latency less that this).
4.  MainStage adds a great deal of latency as compared to a freeware sound engine, SFZ.  See the light blue tests below.  MainStage does not appear to run well on my 2015 MacBook Pro 13” with 8 GB Ram 2.7 i5 processor.  MainStage appears to add approximately 30-40ms latency when playing through the MacBook Pro core audio (no external audio interface).  I have included a snapshot of what MainStage claims to be the resultant latency of the settings (48kHz, 128 buffer size, safety buffer on).  Their screen says the latency is 27.9ms but I am not sure how accurate that number is.
5.  Blutooth seems to add around 20ms of latency over and above the USB/Hairless combination.   But, there are untested variables in this estimate.  For example, is Hairless-Serial working differently and causing more or less latency?  Is the MacBook Bluetooth interface causing more or less latency?  Is the HC-05?  Tough to measure more accurately.
6.  Bluetooth midi to my MacBook Pro through Hairless-Serial is not playable due to 74ms of additional latency (from all factors).

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

Closed 2020-04-29.

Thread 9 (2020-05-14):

Resistor count wrong in doc?

RosesTheN00b, 2020-05-14:
Hey :)
what a cool project. Thank you so much for sharing!
I am currently trying out whether this can be a great raspberry pi project.

In your [overview page](http://bvavra.github.io/MIDI_Accordion/overview/) there are 11x 1k listed. But on the schematic I can only find 9 (8 next to the transistor, 1 bluetooth). Did I forget any somewhere?

Greetings

Sebastian

RosesTheN00b, 2020-05-14:
Created PR #10 for easy fix :-)

bvavra, 2020-05-14:
Thanks - great catch!  I ran through my docs and yeah, can't find where I got that number from.  My only guess is I was playing around with more voltage dividing somewhere and got my numbers mixed up.  Pull request has been merged.

Closed 2020-05-14.

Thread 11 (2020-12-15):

6 channels

denia85, 2020-12-15:
Hi, how to add in unison to channel 1 channel 4. To channel 2 channel 5. To channel 3 channel 6. as a result, you should get 6 channels. I'm not asking you to do it for me just show me the direction

bvavra, 2020-12-15:
Hi denia,

The code can easily be modified to do this - specifically, adding two lines of code near the end of the note_midi function at the bottom of [MIDI_Accordion.ino](https://github.com/bvavra/MIDI_Accordion/blob/master/MIDI_Accordion/MIDI_Accordion.ino) to send multiple noteOn and noteOff commands for multiple channels.  Let me know if this puts you in the right direction or if you'd like another hint. ;)

denia85, 2020-12-15:
> Привет Дения,
>
> Код можно легко изменить для этого - в частности, добавив две строки кода ближе к концу функции note_midi в нижней части [MIDI_Accordion.ino](https://github.com/bvavra/MIDI_Accordion/blob/master/MIDI_Accordion/MIDI_Accordion.ino) для отправки нескольких команд noteOn и noteOff для нескольких каналов. Дайте мне знать, если это приведет вас в нужное русло или если вы хотите получить еще один намек. ;)

Thanks for the answer. but my knowledge is not enough. Tell me more about which lines and where. for example, 1 and 4 channels. I'll do the rest myself

denia85, 2020-12-15:
> Hi denia,
>
> The code can easily be modified to do this - specifically, adding two lines of code near the end of the note_midi function at the bottom of [MIDI_Accordion.ino](https://github.com/bvavra/MIDI_Accordion/blob/master/MIDI_Accordion/MIDI_Accordion.ino) to send multiple noteOn and noteOff commands for multiple channels. Let me know if this puts you in the right direction or if you'd like another hint. ;)

https://github.com/bvavra/MIDI_Accordion/issues/11#issuecomment-745542524

denia85, 2020-12-15:
Thanks for the answer. but my knowledge is not enough. Tell me more about which lines and where. for example, 1 and 4 channels. I'll do the rest myself

bvavra, 2020-12-15:
Change this:

```
if(on) {
  MIDI.sendNoteOn(pitch, midi_vel, channel);
}
else {
  MIDI.sendNoteOff(pitch, midi_vel, channel);
}
```

to this:

```
if(on) {
  MIDI.sendNoteOn(pitch, midi_vel, channel);
  MIDI.sendNoteOn(pitch, midi_vel, channel+3);
}
else {
  MIDI.sendNoteOff(pitch, midi_vel, channel);
  MIDI.sendNoteOff(pitch, midi_vel, channel+3);
}
```

denia85, 2020-12-15:
And the channels themselves 4 5 6 where?

bvavra, 2020-12-15:
This is done automatically, because the channel variable is set to 1,2, or 3.

denia85, 2020-12-15:
Please

denia85, 2020-12-15:
That is enough? Thanks

Closed 2020-12-15.

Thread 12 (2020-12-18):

Several keyboard layout options

denia85, 2020-12-18:
Hi. tell me how to make several keyboard layout options. with a different tone. Five down five up

byte table = 5;
const char left_notes_midi_numbers[10][7][8] = {
  {
    {0,0,0,0,0,0,0,0},//53
    {0,0,0,0,0,0,0,0},//52
    {0,0,0,0,0,0,0,0},//
    {0,0,0,0,0,0,0,0},//
    {0,0,0,0,0,0,0,0},//
    {0,0,0,0,0,0,0,0},
    {0,0,0,0,0,0,0,0}//
  },
  {
    {0,0,0,0,0,0,0,0},//53
    {0,0,0,0,0,0,0,0},//52
    {0,0,0,0,0,0,0,0},//
    {0,0,0,0,0,0,0,0},//
    {0,0,0,0,0,0,0,0},//
    {0,0,0,0,0,0,0,0},
    {0,0,0,0,0,0,0,0}//
  },
  {
    {0,0,0,0,0,0,0,0},//53
    {0,0,0,0,0,0,0,0},//52
    {0,0,0,0,0,0,0,0},//
    {0,0,0,0,0,0,0,0},//
    {0,0,0,0,0,0,0,0},//
    {0,0,0,0,0,0,0,0},
    {0,0,0,0,0,0,0,0}//
  },
  {
    {0,0,0,0,0,0,0,0},//53
    {0,0,0,0,0,0,0,0},//52
    {0,0,0,0,0,0,0,0},//
    {0,0,0,0,0,0,0,0},//
    {0,0,0,0,0,0,0,0},//
    {0,0,0,0,0,0,0,0},
    {0,0,0,0,0,0,0,0}//
  },
  {
    {44,37,39,42,46,47,41,40},//53
    {46,45,36,38,58,43,48,36},//52
    {57,56,56,57,55,58,56,59},//
    {82,48,85,49,54,50,53,40},//
    {52,72,73,51,76,50,79,49},//
    {45,48,101,63,59,47,58,69},
    {52,72,73,51,55,58,56,59}//
  },
  {
    {0,0,0,0,0,0,0,0},//53
    {0,0,0,0,0,0,0,0},//52
    {0,0,0,0,0,0,0,0},//
    {0,0,0,0,0,0,0,0},//
    {0,0,0,0,0,0,0,0},//
    {0,0,0,0,0,0,0,0},
    {0,0,0,0,0,0,0,0}//
  },
  {
    {0,0,0,0,0,0,0,0},//53
    {0,0,0,0,0,0,0,0},//52
    {0,0,0,0,0,0,0,0},//
    {0,0,0,0,0,0,0,0},//
    {0,0,0,0,0,0,0,0},//
    {0,0,0,0,0,0,0,0},
    {0,0,0,0,0,0,0,0}//
  },
  {
    {0,0,0,0,0,0,0,0},//53
    {0,0,0,0,0,0,0,0},//52
    {0,0,0,0,0,0,0,0},//
    {0,0,0,0,0,0,0,0},//
    {0,0,0,0,0,0,0,0},//
    {0,0,0,0,0,0,0,0},
    {0,0,0,0,0,0,0,0}//
  },
  {
    {0,0,0,0,0,0,0,0},//53
    {0,0,0,0,0,0,0,0},//52
    {0,0,0,0,0,0,0,0},//
    {0,0,0,0,0,0,0,0},//
    {0,0,0,0,0,0,0,0},//
    {0,0,0,0,0,0,0,0},
    {0,0,0,0,0,0,0,0}//
  },
  {
    {0,0,0,0,0,0,0,0},//53
    {0,0,0,0,0,0,0,0},//52
    {0,0,0,0,0,0,0,0},//
    {0,0,0,0,0,0,0,0},//
    {0,0,0,0,0,0,0,0},//
    {0,0,0,0,0,0,0,0},
    {0,0,0,0,0,0,0,0}//
  }
};

void setup()
{
  button_minus.setClickHandler(click);
  button_plus.setClickHandler(click);

void loop()
{
  button_minus.loop();
  button_plus.loop();

#ifdef DEBUG
      Serial.print("Note ");
      if(on){
        Serial.print("on: ");
      }
      else {
        Serial.print("off: ");
      }
      Serial.println(pitch);
    #else
 if(on) {
  MIDI.sendNoteOn(pitch, midi_vel, channel);
  MIDI.sendNoteOn(pitch, midi_vel, channel+3);
}
else {
  MIDI.sendNoteOff(pitch, midi_vel, channel);
  MIDI.sendNoteOff(pitch, midi_vel, channel+3);
}
    #endif
  }

}

void click(Button2& btn) {
    if (btn == button_minus) {
      if(table > 0){
        table--;
        #ifdef DEBUG
          Serial.println(table);
        #endif
      }
    } else if (btn == button_plus) {
      if(table < 9){
        table++;
        #ifdef DEBUG
          Serial.println(table);
        #endif
      }
    }
}

denia85, 2020-12-18:
it should be like this .How to make a toggle the left and right variables with a single button
const char left_notes_midi_numbers[][8] = {
  {38,39,57,C5,0,63,0,51},//A0
  {61,Eb5,64,F5,0,0,0,0},//A1 0.0.64.0.0.0
  {66,67,68,69,48,53,0,0},//A2 0.67.0.0.69
  {Bb5,0,85,61,88,0,97,40},//A3
  {0,72,73,38,F3,0,Eb3,37},//A4
  {45,53,0,63,Bb2,32,0,30},//A5
  {99,0,43,63,0,C3,0,0},//A6
  {76,0,79,0,0,0,67,0}//A7
};

const char left_notes_midi_numbers_0[][8] = {
  {38,39,57,71,57,63,0,51},//A0
  {60,62,63,64,0,55,0,0},//A1 0.0.66.0.0.0
  {65,66,67,68,65,53,0,59},//A2 0.63.0.0.68
  {69,0,85,49,88,50,97,40},//A3
  {0,72,73,38,52,0,50,48},//A4
  {45,53,53,63,57,55,53,53},//A5
  {99,69,43,63,0,59,0,65},//A6
  {76,0,79,0,0,0,67,0}//A7
};

const char left_notes_midi_numbers_1[][8] = {
  {0,0,0,0,0,0,0,0},//
  {0,0,0,0,0,0,0,0},//
  {0,0,0,0,0,0,0,0},//
  {0,0,0,0,0,0,0,0},//
  {0,0,0,0,0,0,0,0},//
  {0,0,0,0,0,0,0,0},//
  {0,0,0,0,0,0,0,0},//
  {0,0,0,0,0,0,0,0}//
};

bvavra, 2020-12-18:
Hello,

To do this, you need a new variable that keeps track of which layout you are using:

`int right_key_layout = 0;`

Then, in the loop() function, you need code that scans your button for input and, if the given button is pressed, change the value of the selected layout.  Here is some pseudo code (you may need to adjust for debounce as necessary - there are many Arduino tutorials on how to read button inputs you can use for better examples):

```
int yourButtonPin = 6;
void loop() {

  uint8_t val = digitalRead(yourButtonPin);
  if (val == LOW)//button is pressed
  {
    right_key_layout++;
    if(right_key_layout > maxNumberOfLayouts)
      right_key_layout = 0;
  }

  //keyboard scanning code...
}
```

Then finally, you can use the variable when selecting which notes to play in the note_midi() function:
`pitch = right_notes_midi_numbers[right_key_layout][group][position];`

You can do the same thing for both left and right hands.

denia85, 2020-12-18:
and could you write what and where exactly to write. I've done a lot of work with your code. that's all that's left.

denia85, 2020-12-18:
please

denia85, 2020-12-18:
It should be like this?
int right_key_layout = 0;
char right_hand_pins[] = { 3, 4, 5, 6, 7, 8, 9, 10, 11 };
// array to store up/down status of right keys
int RightKeysStatus[] = {
  B0000000,
  B0000000,
  B0000000,
  B0000000,
  B0000000,
  B0000000,
  B0000000,
  B0000000,
  B0000000
};
//Note: Based on how the opto-interruptors are laid out,
//You will likely have to remap their pitch numbers (53-93)
const char right_notes_midi_numbers[][8] = {
  {82,85,88,82,85,87,82,84},//4 крайний сверху ряд баяна с низу вверх 8 кнопок с права на лево
  {79,81,64,67,57,51,49,54},//11 средний ряд баяна с низу вверх 8 кнопок с права на лево
  {53,58,56,61,60,65,63,68},//5 средний ряд баяна с низу вверх 8 кнопок с права на лево
  {66,72,70,75,73,78,77,82},//6 верхний ряд баяна с низу вверх первые 2 кнопоки с права на лево
  {80,85,84,42,47,54,44,57},//7 нижний ряд баяна с низу вверх первые 8 кнопок
  {65,62,62,59,62,55,56,51},//8 нижний ряд баяна с низу вверх вторые 8 кнопок
  {77,73,74,70,71,67,68,64},//9 нижний ряд баяна с низу вверх 2 кнопоки
  {68,67,86,64,83,61,80,58}//10 средний ряд баяна с низу вверх 8 кнопок с права на лево

};

bvavra, 2020-12-18:
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

bvavra, 2020-12-18:
See above where the changes should be made.  To clarify, the button scanning code may not be correct - please use whatever code makes sense for the button you chose, and look up Arduino tutorials on how to scan it accordingly.

denia85, 2020-12-18:
Thanks I'll try

bvavra, 2021-01-06:
I've not heard any updates in a bit, so I assume this has been addressed.

Closed 2021-01-06.

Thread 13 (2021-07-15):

Synthesizer

gktval, 2021-07-15:
Awesome project! Thank you so much. This has inspired me to create my own. Think I'll try to do it with an MSP430 instead of Arduino, though.

Question: Have you found a synthesizer with various accordion sounds? I was thinking about adding buttons for the registers, but would like to find a program with a library that can support them. For example a clarinet, musette, master, etc.

bvavra, 2021-07-15:
Hiyo, thanks for your interest in this project!

I personally use Reason as my primary driver of virtual instrument sounds, and I've since implemented a button pad that can be configured to change "registers" (if you will), though I personally like to explore other unnatural, more "synthy" sounds for my MIDI accordion since my acoustic accordion covers the natural accordion tone well enough (see my [YouTube channel](https://www.youtube.com/playlist?list=PLwO5aXJYrMqShhljt1XpOR_GsGuI3mNtk) for various examples of my MIDI accordion in action).

However, if you're looking for an authentic accordion around for your virtual instrument, I highly recommend the [Accordions 2 Sample Pack](https://www.bigfishaudio.com/Accordions-2), which I believe to be the gold standard for realistic-sounding MIDI accordion.

Closed 2021-09-15.

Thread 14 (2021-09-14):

missing resistor on parts list

gktval, 2021-09-14:
Just found the missing 2.2k ohm resistor to the bluetooth module. It's in the schematics, just not the parts list.

bvavra, 2021-09-15:
Thanks for catching this!  I updated the parts list on both the [README](https://github.com/bvavra/MIDI_Accordion/blob/master/README.md) and the [Overview page](http://bvavra.github.io/MIDI_Accordion/overview/) accordingly.

Closed 2021-09-15.

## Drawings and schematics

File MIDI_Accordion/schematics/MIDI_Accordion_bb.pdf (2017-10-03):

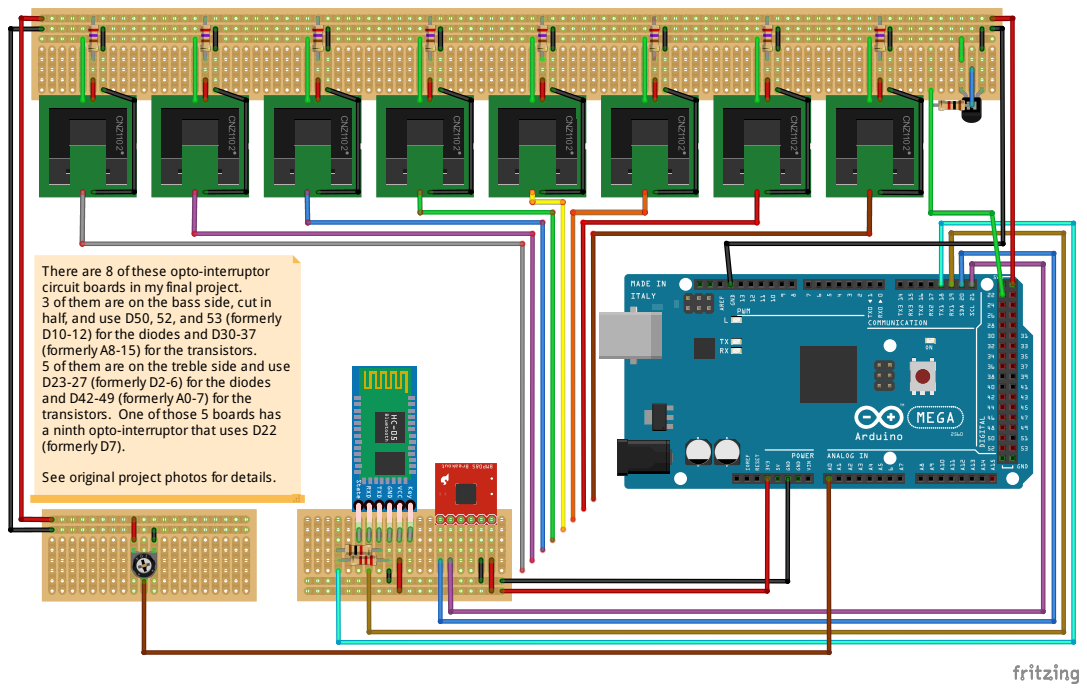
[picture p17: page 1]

There are 8 of these opto-interruptor
circuit boards in my final project.
3 of them are on the bass side, cut in
half, and use D50, 52, and 53 (formerly
D10-12) forthe diodes and D30-37
(formerly A8-15) forthe transistors.
5 of them are on the treble side and use
D23-27 (formerly D2-6) forthe diodes
and D42-49 (formerly A0-7) forthe
transistors. One of those 5 boards has
a ninth opto-interruptorthat uses D22
(formerly D7).

See original project photos for details.

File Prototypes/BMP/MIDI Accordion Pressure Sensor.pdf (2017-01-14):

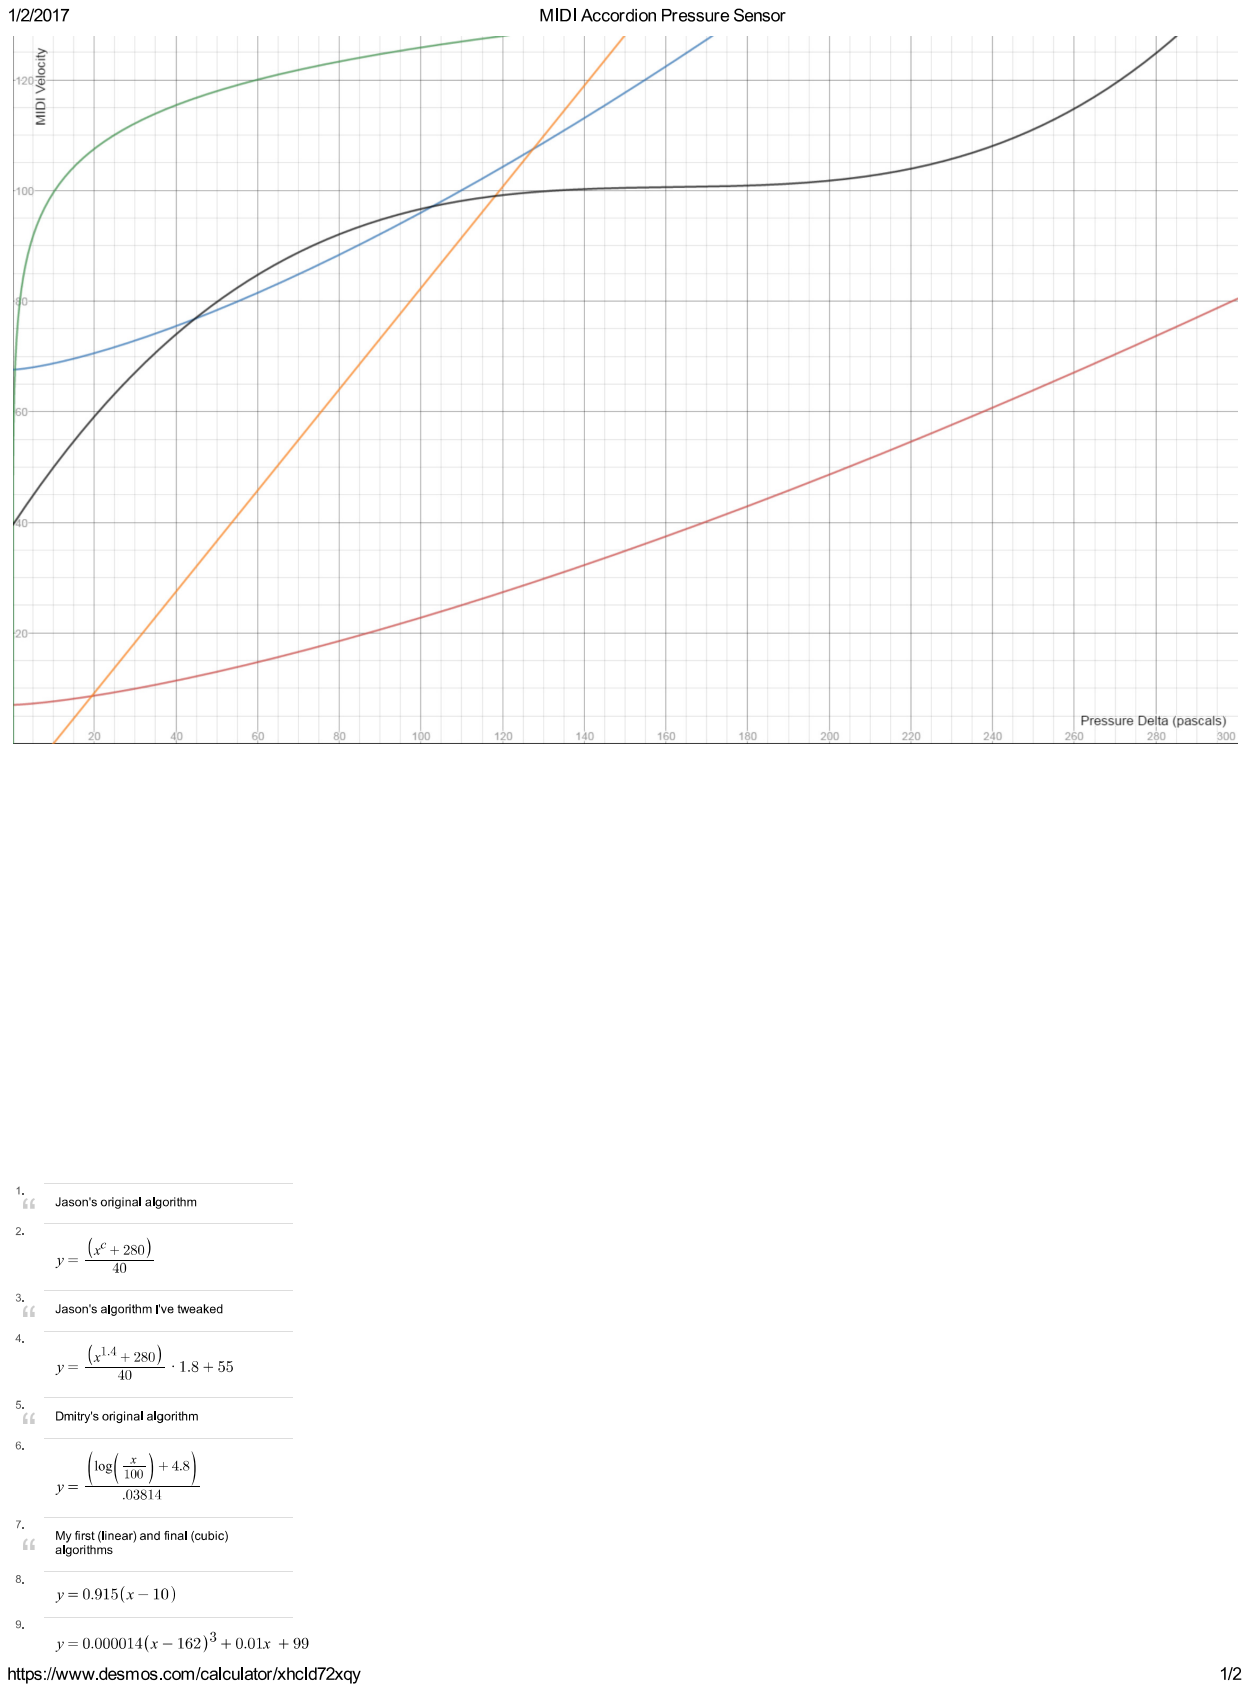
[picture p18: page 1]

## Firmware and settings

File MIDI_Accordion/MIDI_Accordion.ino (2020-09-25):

/*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
 You should have received a copy of the GNU General Public License
 along with this program.  If not, see <http://www.gnu.org/licenses/>.
 *******************************************************************************/

#include <MIDI.h>
#include <midi_Defs.h>
#include <midi_Message.h>
#include <midi_Namespace.h>
#include <midi_Settings.h>
struct MySettings : public midi::DefaultSettings
{
  //By default, the Arduino MIDI Library tries to be smart by 
  //excluding the CC byte if it doesn't change (to save bandwidth).
  //This is a problem when starting up Serial<->MIDI software
  //after starting up the Arduino because we miss the first CC byte.
  //Setting UseRunningStatus to false removes this "feature."
  //See https://github.com/projectgus/hairless-midiserial/issues/16 for details.
  static const bool UseRunningStatus = false;
  // Set MIDI baud rate. MIDI has a default baud rate of 31250,
  // but we're setting our baud rate higher so that the Serial<->MIDI software 
  // can properly decode and read outgoing MIDI data on the computer.
  static const long BaudRate = 115200;
};

//#define DEBUG//uncomment this line to print serial messages, comment to send MIDI data
//#define BLUETOOTH//uncomment this line to send MIDI data via bluetooth instead of USB
//#define BMP//uncomment this line to use the BMP180 to add dynamics via bellows
//#define JOYSTICK//uncomment this line to use a joystick as a pitch-bend controller

#ifdef BLUETOOTH
  MIDI_CREATE_CUSTOM_INSTANCE(HardwareSerial, Serial1, MIDI, MySettings);
#else
  MIDI_CREATE_CUSTOM_INSTANCE(HardwareSerial, Serial, MIDI, MySettings);
#endif

char left_hand_pins[] = { 53, 52, 50 };
// array to store up/down status of left keys
int LeftKeysStatus[] = {  
  B0000000,
  B0000000,
  B0000000
};
//Note: Based on how the opto-interruptors are laid out,
//You will likely have to remap their pitch numbers (36-59)
//36-47 are the bass notes, 48-59 are the chord notes
const char left_notes_midi_numbers[][8] = {
  {38,39,40,41,50,51,52,53},//53
  {46,47,36,37,58,59,48,49},//52
  {42,43,44,45,54,55,56,57} //50
};

char right_hand_pins[] = { 23, 25, 27, 26, 24, 22 };
// array to store up/down status of right keys
int RightKeysStatus[] = {  
  B0000000,
  B0000000,
  B0000000,
  B0000000,
  B0000000,
  B0000000
};
//Note: Based on how the opto-interruptors are laid out,
//You will likely have to remap their pitch numbers (53-93)
const char right_notes_midi_numbers[][8] = {
  {65,64,62,60,59,57,55,53},//23
  {79,77,76,74,72,71,69,67},//25
  {70,68,66,63,61,58,56,54},//27
  {93,91,89,88,86,84,83,81},//26
  {90,87,85,82,80,78,75,73},//24
  {92,0,0,0,0,0,0,0}        //22
};

void setup()
{
  #ifdef DEBUG
    Serial.begin(9600);
  #else
    MIDI.begin();
    //If we're sending MIDI over Serial1, open Serial for additional debugging
    #ifdef BLUETOOTH
      Serial.begin(9600);
    #endif
  #endif
  //Digital pins start turned off
  for (int i=0; i<sizeof(left_hand_pins);i++){ 
    pinMode(left_hand_pins[i],OUTPUT);
    digitalWrite(left_hand_pins[i], LOW);
  }
  for (int i=0; i<sizeof(right_hand_pins);i++){ 
    pinMode(right_hand_pins[i],OUTPUT);
    digitalWrite(right_hand_pins[i], LOW);
  }

  DDRL = B00000000;  // PortL (42-49) as input (for left hand)
  PORTL = B11111111; // turn on pullup resistors

  DDRC = B00000000;  // PortC (30-37) as input (for right hand)
  PORTC = B11111111; // turn on pullup resistors

  #ifdef BMP
    init_BMP();
  #endif

  #ifdef JOYSTICK
    init_joystick();
  #endif
}

//MIDI Control Change code for expression, which is a percentage of velocity
const int CC_Expression = 11;
int prev_expression = 127;
//The BMP_180 is very sensitive, so readings can vary wildly from sample to sample.
//We're getting around this by computing and sending the average of bmp_sample_rate samples.
//A smaller bmp_sample_rate is more granular, but allows more "noise" to come in.
//A larger bmp_sample_rate is less granular, but has a smoother contour.
//Setting bmp_sample_rate too large may also lose the amount of perceived expression
//and create a noticable delay between squeezing the bellows and hearing the volume change,
//resulting in choppy crescendos and decrescendos.
//Tweak this value as needed.
const int bmp_sample_rate = 5;
int expression_avg[bmp_sample_rate];
int e = 0;

int joystick_prev_val = 0;

void loop()
{
  #ifdef BMP
    //Read pressure from the BMP_180 and convert it to MIDI expression
    int expression = get_expression(prev_expression);
    
    //Ignore it if it didn't change
    if(expression != prev_expression) {
      expression_avg[e] = expression;
      //Only send MIDI CC every bmp_sample_rate times, 
      //but send the average of the last bmp_sample_rate deltas
      if (e == bmp_sample_rate - 1){
        expression = 0;
        for (int i=0; i<bmp_sample_rate; i++){
          expression += expression_avg[i];
        }
        expression = expression/bmp_sample_rate;
        
        #ifdef DEBUG
          Serial.print("Expression Change: ");
          Serial.println(expression);
        #else
          MIDI.sendControlChange(CC_Expression,expression,1);
          //Don't let bass overpower melody
          MIDI.sendControlChange(CC_Expression,constrain(expression-6,0,127),2);
          //Don't let chords overpower melody
          MIDI.sendControlChange(CC_Expression,constrain(expression-12,0,127),3);
        #endif
        prev_expression = expression;
        e = 0;
      }
      else {
        e = e + 1;
      }
    }
  #endif

  #ifdef JOYSTICK
    int pitch_bend_val = scan_joystick();
    if(pitch_bend_val != joystick_prev_val) {
      #ifdef DEBUG
        Serial.print("Pitch Bend Change: ");
        Serial.println(pitch_bend_val);
      #else
        //Comment and uncomment to select which channels you want pitch bend to affect.
        MIDI.sendPitchBend(pitch_bend_val, 1);
        //MIDI.sendPitchBend(pitch_bend_val, 2);
        //MIDI.sendPitchBend(pitch_bend_val, 3);
        joystick_prev_val = pitch_bend_val;
      #endif
    }
  #endif

  //Alternate between scanning the left and right hand pins 
  //to reduce necessary delay between reads
  for (int i=0; i<6;i++){ 
    scan_pin(right_hand_pins[i], i, RightKeysStatus[i], false);
    scan_pin(left_hand_pins[i%3], i%3, LeftKeysStatus[i%3], true);
  }
}

byte reg_values = 0;

//Read the analog port value for the given pin
//If something changed, trigger MIDI signal
void scan_pin(int pin, int index, byte PinStatus, bool left) {
  //TODO - I wonder if we can replace this with direct port write for even better performance?
  digitalWrite(pin, HIGH);
  //A slight delay is needed here or else we'll be reading the previous pin
  delayMicroseconds(300);//was able to cut this in half by alternating between left and right
  if (left) {
    reg_values = ~PINL;
  }
  else {
    reg_values = ~PINC;
  }
  digitalWrite(pin, LOW);

  //check if something changed
  if (reg_values != PinStatus){ 
    //if the byte value is greater, we're turning the note on; else, turning it off.
    if (reg_values > PinStatus){
      //using bit-wise OR to send modified bits only
      check_key(reg_values ^ PinStatus, index, true, left); 
    }
    else {
      check_key(reg_values ^ PinStatus, index, false, left);
    }
  }
}

//Check to see which bits have changed and send the appropriate midi message
//Instead of iterating the array from 0-7, use binary search to find the modified bits faster
void check_key(int reg, int group, boolean on, boolean left){
  // saving 4 iterations, dividing byte by 2
  if (reg & 0xF0) {
    for(int i=0; i<4; i++){
      if ((reg >> 4+i) & 1){
        note_midi(group, i+4, on, left);
      }
    }
  }
  else if (reg & 0x0F) { 
    for(int i=0; i<4; i++){
      if ((reg >> i) & 1){
        note_midi(group, i, on, left);
      }
    }
  }
}

void note_midi(int group, int position, boolean on, boolean left){
  int pitch;
  int channel = 1;
  int midi_vel = 127;

  if (left){
    if (on){
      LeftKeysStatus[group] |= (1 << position);  //setting bit value
    }
    else {
      LeftKeysStatus[group] &= ~(1 << position);  //setting bit value
    }
    pitch = left_notes_midi_numbers[group][position];
    if(pitch < 48) {
      midi_vel = 120;//Don't let bass overpower melody
      channel = 2;
    }
    else {
      midi_vel = 110;//Don't let chords overpower melody
      channel = 3;
    }
  }
  else{
    if(on) {
      RightKeysStatus[group] |= (1 << position);  //setting bit value
    }
    else {
      RightKeysStatus[group] &= ~(1 << position);  //setting bit value
    }
    pitch = right_notes_midi_numbers[group][position];
    channel = 1;
  }

  if (pitch){
    #ifdef DEBUG
      Serial.print("Note ");
      if(on){
        Serial.print("on: ");
      }
      else {
        Serial.print("off: ");
      }
      Serial.println(pitch);
    #else
      if(on) {
        MIDI.sendNoteOn(pitch, midi_vel, channel);
      }
      else {
        MIDI.sendNoteOff(pitch, midi_vel, channel);
      }
    #endif
  }

}

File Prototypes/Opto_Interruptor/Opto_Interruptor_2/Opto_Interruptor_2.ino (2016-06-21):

/* 
* Matrix of Interruptors - it's recommended to try 2x2, 1x4, and 4x1, but this code supports up to 8x4 as written.
* At this point much of this code is pulled directly from AccordionMega's code.
*/

//This prototype currently supports 4 digital pins, 
//but you can add as many as you want by extending the two arrays below:
char DIGITAL_COLUMNS[] = { 9, 10, 11, 12 };
int KeysStatus[] = {  
  B0000000,
  B0000000,
  B0000000,
  B0000000
};

//this is the value of all pins from the analog port (Note: analog pins 7 and 6 don't exist on UNO)
//B00000000
//B76543210
byte reg_values = 0;

void setup()
{
  Serial.begin(9600);
  //Digital pins start turned off
  for (int i=0; i<sizeof(DIGITAL_COLUMNS);i++){ 
      pinMode(DIGITAL_COLUMNS[i],OUTPUT);
      digitalWrite(DIGITAL_COLUMNS[i], LOW);
  }

  //Arduino UNO has different port letters than the MEGA,
  //so this check is required for this code to be compatible with both boards.
  #if defined (__AVR_ATmega328P__)//UNO
    DDRC = B00000000;  // PortC as input (for Arduino Uno)
    PORTC = B11111111; // turn on pullup resistors
  #elif defined (__AVR_ATmega2560__)//MEGA
    DDRF = B00000000;  // PortF as input (for Arduino Mega)
    PORTF = B11111111; // turn on pullup resistors
  #endif
}

void loop()
{
  for (int i=0; i<sizeof(DIGITAL_COLUMNS);i++){ 
    //TODO: I wonder if we can replace this with a direct port write for better performance?
    digitalWrite(DIGITAL_COLUMNS[i], HIGH);
    delayMicroseconds(500);//This delay value has proven to work with the ITR9608
    
    #if defined (__AVR_ATmega328P__)
      reg_values = ~PINC;
    #elif defined (__AVR_ATmega2560__)
      reg_values = ~PINF;
    #endif
    
    digitalWrite(DIGITAL_COLUMNS[i], LOW);

    if (reg_values != KeysStatus[i]){
      if (reg_values > KeysStatus[i]){ //if it's greater, we're turning the note on; else, turning it off.
        check_key(reg_values ^ KeysStatus[i],i,true);  //using bit-wise OR to send modified bits only
      }
      else {
        check_key(reg_values ^ KeysStatus[i],i,false); //using bit-wise OR to send modified bits only
      }           
    }
  }
}

//Instead of iterating the array from 0-7, use a binary search to find the modified bits faster
void check_key(int reg, int group, boolean up){
   // saving 4 iterations, dividing byte by 2
   if (reg & 0xF0) {
     for(int i=0; i<4; i++){
       if ((reg >> 4+i) & 1){
         note_midi(group,i+4,up);
       }
     }
   }
   else if (reg & 0x0F) { 
    for(int i=0; i<4; i++){
       if ((reg >> i) & 1){
         note_midi(group,i,up);
       }
     }     
   }
}

//This is the mapping of pitches on the right hand of the accordion.
//Note: The right two most bits will always turn on for the UNO because those pins don't exist.
//You can stop this from happening by commenting out the right-most two values in the top row.
const char right_notes_midi_numbers[][8] = {
  {60,59,58,57,56,55,54,53},
  {68,67,66,65,64,63,62,61},
  {76,75,74,73,72,71,70,69},
  {84,83,82,81,80,79,78,77},
  {92,91,90,89,88,87,86,85},
  {0,0,0,0,0,0,0,93}
};

char notes_to_play;

//Set the state of the notes pressed and print data for the new note
void note_midi(int group, int position, boolean on){
  
  int pitch;
  String str_warn;
  byte midi_channel = 1;
  char midi_cmd;
  int midi_vel;

  pitch = right_notes_midi_numbers[group][position];

  if(on) {
    str_warn = "Note on ";
    midi_cmd = midi_channel | 0x90;
    KeysStatus[group] |= (1 << position);  //setting bit value
    Serial.print(" Changed Status: ");
    Serial.println(KeysStatus[group], BIN);
    midi_vel = 127;
  }
  else if(~on) {
    str_warn = "Note off ";
    midi_cmd = midi_channel | 0x80;
    KeysStatus[group] &= ~(1 << position);  //setting bit value
    Serial.print(" Changed Status: ");
    Serial.println(KeysStatus[group], BIN);
    midi_vel = 0;
  }
    
  Serial.print(str_warn);
  Serial.print(pitch,DEC);
  Serial.print(" Vel: ");
  Serial.println(midi_vel);
  Serial.print(" Group: ");
  Serial.println(group);
  Serial.print(" Position: ");
  Serial.println(position);
  
  notes_to_play = right_notes_midi_numbers[group][position];
  if (notes_to_play){
    //This is where we'd print the MIDI Note On/Off command with the ArduinoMIDI library
    //See the Opto-Interruptor MIDI prototype or the final project for more info.
    
    //Serial1.print(midi_cmd, BYTE);
    //Serial1.print(notes_to_play, BYTE);
    //Serial1.print(midi_vel, BYTE);
    Serial.print(" ");
    Serial.println(notes_to_play,DEC);
  }

}

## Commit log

2016-04-10 Added MIDI prototype sketch and code
    [MIDI_Tutorial.fzz]
2016-04-10 Set MIDI velocity and channel as global variables
2016-04-10 Added Bluetooth Tutorial 1
    [Bluetooth_Tutorial.fzz]
2016-04-10 Added Bluetooth Tutorial 2 circuit and sketch
    [Bluetooth_Tutorial_2.fzz]
2016-06-13 Initial commit of original opto-interruptor prototypes
    [Interruptor_1.fzz, Interruptor_1_rev.fzz, Interruptor_4_Uno.fzz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]
2016-06-13 Replaced three opto-interruptor prototypes with a single one that's compatible with both the UNO and the MEGA
    [Opto_Interruptor_1.fzz, Opto_Interruptor_1_rev.fzz]
2016-06-15 Condensed other opto-interruptor tutorials
    [Interruptor_4_Uno.fzz, Interruptor_4_Uno_AccordionMega.fzz]
2016-06-15 Added datasheets for transistor and opto-interruptor
2016-06-20 Updated Fritzing sketches to use new parts
    [Bluetooth_Tutorial.fzz, Bluetooth_Tutorial_2.fzz, Opto_Interruptor_1.fzz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]
2016-06-21 Renamed tutorial from 4 to 2 (to match sequence instead of count, which could be variable). Also cleaned up the tutorial.
    [Interruptor_4_Uno.fzz, Opto_Interruptor_2.fzz]
2016-06-21 More minor doc changes
    [Opto_Interruptor_2.fzz]
2016-07-01 Replaced debug compiled variable wirh #define; set MIDI channel correctly
    [MIDI_Accordion.ino]
2016-07-24 Fixed up Fritzing diagrams for 2x2 opto-interruptors
    [Opto_Interruptor_2_breadboard.fzz, Opto_Interruptor_2_schematic.fzz]
2016-08-10 Updated bass side pitch mapping to match physical opto-interruptor layout
2016-08-10 Reversed bass side opto-interruptor mapping (mistook bass buttons with chord buttons)
    [MIDI_Accordion.ino]
2016-08-28 Remapped chord button pitches again according to resulting output.
2016-10-13 Fixed MIDI tutorial to only use the library begin and not Serial.begin, which includes overriding the baud rate in the library settings.
    [MIDI_Tutorial.ino]
2016-10-22 Fixed bass button map (again)
    [MIDI_Accordion.ino]
2016-10-24 Use custom MIDI instance instead of overriding baud rate with redundant serial call. Also upped the delay between port reads to prevent unwanted notes from playing (hopefully temporarily)
    [MIDI_Accordion.ino]
2016-11-20 Moved final right hand pitch to the proper column based on my wiring (still need to remap it and the other right hand pitches)
2016-11-27 Re-mapped right hand pitches according to circuit layout
2016-12-07 Fixed left hand mappings... again (hopefully for the final time). Also fixed a typo in the right hand mapping. Was able to test reducing the delay back down to 300us.
    [MIDI_Accordion.ino]
2016-12-09 Swapped chord and bass button mappings, and lowered the velocity on them (to ensure right hand doesn't get drowned out)
    [MIDI_Accordion.ino]
2016-12-28 First working BMP tutorials. MIDI tutorial still has a ways to go.
    [BMP_Tutorial.fzz]
2016-12-29 Updated both BMP tutorials to read temperature every time, which fixes the previous problem where pressure took a long time to reset to the calibrated pressure. Also added other pressure <-> velocity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
    [BMP_180.ino, BMP_Tutorial.ino, BMP_Tutorial_2_MIDI.ino]
2016-12-30 renamed second BMP tutorial from MIDI to Velocity
2016-12-30 Created third BMP tutorial to implement and test async pressure measurements; updated final project to use it
2016-12-31 Fixed bug in sending MIDI CC data. Implemented algorithm to only send CC changes in averaged batches.
    [BMP_180.ino, BMP_Tutorial_3_MIDI.ino, MIDI_Accordion.ino]
2016-12-31 Replaced my pressure mapping algorithm with the one used in AccordionMega_USB_Keyb and made tweaks - sounds and feels a lot more realistic, but still needs some minor tweaks.
    [BMP_180.ino, MIDI_Accordion.ino]
2017-01-01 Playing around with different formulas for mapping pressure to velocity
2017-01-02 Still tweaking pressure mapping function. Also minor doc updates
2017-01-02 Final pressure mapping formula
2017-01-07 Added first draft of basic assembly/installation instructions
2017-01-07 Fixed assembly instruction numbering
2017-01-11 Commiting this prototype for the sake of having it in source control
2017-01-11 Also adding this power switch sketch to source control
    [Power_Tutorial.fzz]
2017-01-11 Deleting power switch sketch
    [Power_Tutorial.fzz]
2017-01-12 Created and added final project schematics and example board design - includes original fritzing file, png image, and pdf documents of each
    [MIDI_Accordion.fzz]
2017-01-12 Linked schematics to README and added condensed BoM
2017-01-14 Moved tutorials around a bit
    [BMP_Tutorial.fzz, Bluetooth_Tutorial.fzz, Bluetooth_Tutorial_2.fzz]
2017-01-14 Added Pressure Sensor graph to BMP tutorials folder
2017-08-13 Move digital pins from 2-13 to 22-53 to free up PWM pins
2017-09-27 Added tutorials for using a joystick to bend pitch
2017-09-27 Added joystick support to apply "whammy bar"-style pitch bend to selected MIDI channels
2017-10-03 Updated schematics and breadboard docs to move pins and include joystick
    [MIDI_Accordion.fzz]
2017-11-19 Don't send pitch bend MIDI data in #debug mode
2020-09-15 Add minor comments to velocity tutorial
2020-09-15 Update link to Arduino MIDI Library docs
2020-09-15 Add datasheet for joystick used for pitch bend
2020-09-25 Reset config vars to defaults. Add Joystick instructions to Quick Guide in README
    [MIDI_Accordion.ino, Pitch_Bend.ino]
2021-09-15 Issue #14 - Added 2k Ohm Resistor to Parts List
    Also fixed number of 1k Ohm resisters per Issue #9.

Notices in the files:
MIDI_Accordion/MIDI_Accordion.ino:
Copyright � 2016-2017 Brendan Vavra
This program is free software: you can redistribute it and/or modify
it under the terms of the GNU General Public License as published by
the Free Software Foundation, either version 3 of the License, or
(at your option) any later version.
